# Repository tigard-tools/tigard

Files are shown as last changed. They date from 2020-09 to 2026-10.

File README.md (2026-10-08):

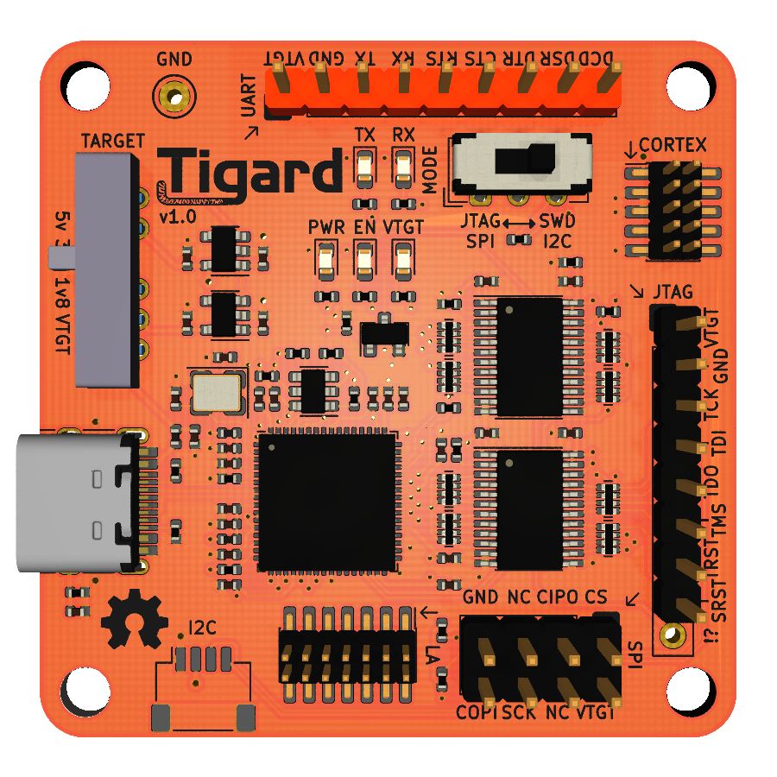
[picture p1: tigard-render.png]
Tigard PCB Render


# Tigard

An FTDI FT2232H-based multi-protocol tool for hardware hacking.

# Objectives

There are plenty of -232H series breakout boards, but they are generally designed to be an easy way to adapt it to a specific use, and not designed for regularly plugging in to all different target systems.

The two exceptions are the Exodus Intelligence Hardware Interface Board which is not open hardware or commercially available, and [TIMEP](https://github.com/Matir/timep) which is the origin and heritage of this project.

# Contents
- [Software Features](#software)
- [Hardware Features](#hardware-features)
- [Usage](#usage)
  - [Hardware Hookup](#hardware-hookup)
  - [Switches](#switches)
  - [UART](#uart)
  - [SPI](#spi)
  - [I2C (on I2C or SPI header)](#i2c-on-i2c-spi-or-jtag-header)
  - [JTAG Debug (on JTAG or CORTEX header)](#jtag-debug-on-jtag-or-cortex-header)
  - [JTAG Boundary Scan (on JTAG or CORTEX header)](#jtag-boundary-scan-on-jtag-or-cortex-header)
  - [SWD (on CORTEX header)](#swd-on-cortex-header)
  - [iCE40 Programming](#ice40-programming)
  - [AVR ISP](#avr-isp)
- [Debugging](#debugging)
- [Pinouts](#pinouts)
- [Stripes and Tails](#stripes-and-tails)
- [Dens (cases)](#dens)
- [Serial Numbers](#serial-numbers)
- [Getting Tigard](#getting-tigard)

# Software Features

In general, Tigard was designed to work as-is with several tools and libraries that already support the x232H family of chips. This includes:

* USB-Serial drivers for UART access
* OpenOCD and URJTAG for JTAG
* Flashrom, libmpsse, pyftdi and other tools for SPI interfaces
* libmpsse and pyftdi for I2C interfaces
* iceprog for ice40 FPGAs
* avrdude for AVR microcontrollers

Also, users have used Tigard with [Mitou jtag](/../../issues/79), [VSCode](/../../pull/75), and [SPI via FTDI](/../../issues/40)

# Hardware Features

Highlights:

* Dual-port, with one dedicated to UART and the second shared with other interfaces
* High-performance directional level shifters for 1.8 to 5.5v operation
* Switch to choose between on-board 1.8, 3.3, and 5.0v supplies and vTarget
* Switch to choose between SPI/JTAG and I2C/SWD modes
* Logic analyser port to observe device-level signals (v1.0 and later)
* Indicator lights to aid debugging

# Usage

## Hardware Hookup

Starting with the board completely disconnected:

1. Connect board to target system with clips or jumper wires
1. Select the correct mode either SPI/JTAG or SWD/I2C
1. Ensure that the voltage switch is in VTGT mode
1. Plug in the USB cable. The PWR and EN LEDs will illuminate
1. Power on your target.
1. If you connected VTGT to your target, the VTGT LED will illuminate. If not, you can now select your voltage with the voltage switch

## Switches
There are two switches on Tigard to set the mode of operation. One controls voltage, one controls how several of the IO pins are wired. Both need to be set properly for a specific use mode. Details are in each of the interface sections further below, but here is a summary of the modes and their uses:

#### Voltage Switch

This switch chooses the reference voltage for the level shifters and the target system:
* 1V8, 3V3, and 5V all apply a voltage to the VTGT pin.
* VTGT disconnects the VTGT pin from supplies, and depends on the wire connected to the target to set the level shifter voltage.

This results in 3 distinct use cases:
1. **Target-Powered:** Set the switch to VTGT and connect the VTGT wire to the **powered** target. The **target** powers the level shifters.
1. **Tigard-Powered:** Set the switch to a voltage, and connect the VTGT to the **unpowered** target. **Tigard** supplies power to the target.
1. **Self-Powered:** Set the switch to a voltage, but do NOT connect the VTGT wire. **Tigard** powers its own level shifters. **Target** powers itself.

#### Mode Switch

This switch controls how some of the I/O pins are connected for specific uses:

* When set to JTAG/SPI mode:
  * All signals run straight through
  * CORTEX and JTAG headers are wired for normal JTAG
  * JTAG and SPI headers can be used for SPI
* When set to SWD/I2C mode:
  * DO and DI are wired together to create SWDIO or SDA
  * CORTEX and JTAG headers can be used for SWD
  * JTAG and SPI headers can be used for I2C

## UART

#### Hookup:

* In most cases, you need pins 2,3,and 4 of the UART header - Ground, TX, and RX. Connect these to your target
* If you have a VCC header on your target, connect pin 1 - VTGT to it, and slide the voltage selector to VTGT
* If you don't have a VCC header, leave the VTGT wire disconnected, and choose your target voltage with the selector

#### Software:

The first of the two ports is connected to the UART header. When you plug Tigard in, you will see two serial devices show up - the first one is the one you want. Start your software using the appropriate serial port. For example:

```bash
screen /dev/ttyUSB0 115200
```

## SPI

#### Hookup:

The SPI/I2C header is laid out to be the same orientation as the pins on a standard 8-pin SPI flash chip, making it easy to attach clips or sockets.

* Select SPI/JTAG on the mode selection switch
* Connect your clip or socket to the header. Pay attention to pin 1, which is usually marked on sockets or has a red/highlighted wire on ribbon cables
* Connect your clip to the target or insert your chip into the socket
* If you're doing this in-circuit, you *must* take extra precautions to make sure no other device is communicating with the SPI device.
* If you're using a clip in-circuit and the target is powered on, choose the VTGT option on the voltage slider
* If you're using a zif socket, or clip with a powered-off target, choose the voltage on the voltage slider. 

#### Software:

flashrom is the most common tool for SPI flash dumps. However, while pervasive, it is very slow and inefficient.

```bash
flashrom -p ft2232_spi:type=2232H,port=B,divisor=4
```

libmpsse is a powerful library for controlling the MPSSE, or high speed serial pins of the x232H series. However, it is no longer recommended because of a large number of dependencies

pyftdi is a new and simple interface very similar to libmpsse:

```python
from pyftdi.ftdi import Ftdi
Ftdi.show_devices()
from os import environ
ftdi_url = environ.get('FTDI_DEVICE', 'ftdi://ftdi:2232:1:23f/2')
from spiflash.serialflash import SerialFlashManager
flash=SerialFlashManager.get_flash_device(ftdi_url)
print("Flash device: %s @ SPI freq %0.1f MHz" % (flash, flash.spi_frequency/1E6))
f=open("data.bin","wb")
f.write(flash.read(0,len(flash)))
f.close()
```

## I2C (on I2C, SPI, or JTAG header)

#### Hookup:

The I2C header (on hardware versions 1.0 and later) is compatible with [Sparkfun's Qwiic](https://www.sparkfun.com/qwiic) and [Adafruit's STEMMA QT](https://learn.adafruit.com/introducing-adafruit-stemma-qt/what-is-stemma-qt) system:

* Connect a 4-pin JST SH compatible cable into the I2C connector
* Connect the other end to your STEMMA QT, Qwiic, or other I2C device

In addition, the SPI header is laid out to be the same orientation as the pins on most 8-pin I2C chips, making it easy to attach clips or sockets:

* Connect your clip or socket to the header. Pay attention to pin 1, which is usually marked on sockets or has a red/highlighted wire on ribbon cables
* Connect your clip to the target or insert your chip into the socket

Finally, the JTAG header can also be used to get the I2C signals on .1" individual pins:

* Connect the 8-wire JTAG harness to the JTAG connector
* Connect the white SCL and grey SDA wires to your target's I2C pins

In either case, you need to set the Tigard switches properly:

* Select I2C on the mode selection switch
* If you're attaching to a device in-circuit and the target has its own power, choose the VTGT option on the voltage slider
* If you're attaching a standalone sensor, socket, or clip with a powered off target, choose the correct voltage on the voltage slider

#### Quirks:

The FT2232H has a very limited I2C implementation. I2C depends on shared I/O lines using open collector/open drain instead of push-pull-tristate I/O, but the FT2232H doesn't support that well. Therefore:

* Only controller operation is supported, not Device
* Tigard may not play nice if there are other controllers present on the I2C interface
* Clock stretching is not supported
* The I2C switch ties the DI and DO lines together so that it can do bidirectional communication
* The pullup resistors are not included since they are usually located on the target, and the weak pullups on the level shifters are sufficient

#### Hacks:

To accomodate both I2C and SWD, the DI and DO lines are combined through resistor R16. This is required for SWD and generally acceptable for I2C. 

Many I2C targets already have pullup resistors. In addition, all of Tigard's I/O pins have a weak 100K ohm pullup. In testing, this has been sufficient for both in-circuit and external use of most I2C devices. If you need stronger pullups on I2C, you can temporarily add them by pulling up COPI and SCK on the SPI header, or TCK and TDI on the JTAG header.

#### Software:

libmpsse is a powerful library for controlling the MPSSE, or high speed serial pins of the x232H series. However, it is no longer recommended because of a large number of dependencies

pyftdi is a new and simple interface very similar to libmpsse:

```python
from pyftdi.ftdi import Ftdi
Ftdi.show_devices()
from os import environ
ftdi_url = environ.get('FTDI_DEVICE', 'ftdi://ftdi:2232:1:23f/2')
from i2cflash.serialeeprom import SerialEepromManager
flash = SerialEepromManager.get_flash_device(ftdi_url,'24AA32A',0x50)
flash.write(5,10)
flash.read(0,32)
```

## JTAG Debug (on JTAG or CORTEX header)

#### Hookup:

The JTAG header is laid out with pins in the same order as the FTDI I/O pins are labeled, in order to be consistent with many other x232H breakout boards.

In additon, the CORTEX header is also wired as a standard ARM 10-pin JTAG header.

Be sure to select JTAG on the mode selection switch. This makes sure that TDI and TDO are separated, and ensures that TMS is wired properly to the CORTEX header. Otherwise, the standard hookup sequence applies.

#### Software:

[OpenOCD](https://openocd.org/) is a powerful tool for On-Chip Debugging of ARM, MIPS, and some other architectures.

**NOTE: These OpenOCD configs require OpenOCD v0.12+**. Previous versions may use the now-deprecated commands last updated in [this commit](https://github.com/tigard-tools/tigard/commit/5e5722944c8c1ec73b0fa85d574793300c23b3ce). [Future versions will deprecate some of these commands](https://github.com/tigard-tools/tigard/pull/86).

The appropriate configuration file (make this a link to the file) should look like:

```
adapter driver ftdi
transport select jtag
ftdi vid_pid 0x0403 0x6010
ftdi channel 1
adapter speed 2000
ftdi layout_init 0x0038 0x003b
ftdi layout_signal nTRST -data 0x0010
ftdi layout_signal nSRST -data 0x0020
```

To use it with openocd:

```bash
openocd -f tigard-jtag.cfg
```

[Black Magic Debug](https://codeberg.org/blackmagic-debug/blackmagic) is an alternative for OpenOCD that supports automatic identification and configuration of a huge number of devices. The Black Magic Debug App can do this through Tigard:

```
blackmagic -l # list probes, you should see Tigard listed
blackmagic -c tigard -t # list connected devices, you should see your target
blackmagic -c tigard # start the server, it will tell you a port to connect GDB to
gdb-multiarch --eval-command="tar ext :2000" --eval-command="att 1" # to start gdb and connect
```

## JTAG Boundary Scan (on JTAG or CORTEX header)

Boundary scan can be used to take control of a device to set I/O pin state (`EXTEST`), or to view the state of them during device operation (`SAMPLE`).

#### Hookup:

The hookup is the same as described in section [JTAG Debug (on JTAG or CORTEX header)](#jtag-debug-on-jtag-or-cortex-header).

The pinout is compatible with the `Olimex ARM-USB-OCD` running on the `B` interface.

#### Software:

[UrJTAG](https://urjtag.sourceforge.io/) is open-source jtag control software geared toward low-level and boundary scan use.

We need to tell UrJTAG Tigard's VID and PID, as well as the fact that JTAG is on interface 1 (default is 0). Due to a bug it seems that TCK is miscalculated and is actually running 5 times what you select - 500khz in the case below.

```
jtag> cable ft2232 vid=0x403 pid=0x6010 interface=1
Connected to libftdi driver.
jtag> frequency 100000
Setting TCK frequency to 100000 Hz
jtag> detect
IR length: 5
Chain length: 1
Device ID: 00010110001101010010001001001111 (0x1635224F)
  Unknown manufacturer! (00100100111) (/usr/share/urjtag/MANUFACTURERS)
jtag> 
```

The [TopJTAG](http://www.topjtag.com/) software is one of the easier to use options, but is commercial ($100) and Windows-only. This includes a "waveform view" that allows you to view arbitrary pin states as if you had a logic analyzer on the device while it is running. If using TopJTAG, set the following as the JTAG connection:

* `Connection`: Generic FTDI FT2232
* `Device`: Tigard V1.0 B
* `Static Pins`: Olimex ARM-USB-OCD
* `TCK Freq`: 2 MHz (adjust as needed)

An open-source option that supports Tigard is [JTAG Boundary Scanner](https://github.com/viveris/jtag-boundary-scanner) which offers a Windows GUI, but the backend library is cross-platform (however written in C). This library offers many features such as an ability to talk to SPI devices attached to the target chip, where the SPI interface is run using JTAG boundary scan (warning - slow!). 

Alpha Python bindings for this library are available in [PyJTAGBS](https://github.com/colinoflynn/pyjtagbs). Using Tigard from Python for checking the scan chain for example:

```python
from jtagbs import JTAGCore, JTAGBS

interface = JTAGCore()
jtag = JTAGBS(interface)

probes = jtag.list_available_probes()
print(probes)

jtag.open_probe('Tigard V1.0 B')
jtag.init_scanchain()

print(jtag.list_devids())
```

See the PyJTAGBS documentation for further examples of loading BSDL files required to toggle specific pins. The listed probes should be `'Tigard V1.0 A TG100065A'` and `'Tigard V1.0 B TG100065B'` if the correct drivers are loaded.

## SWD (on CORTEX header)

#### Hookup:

The SWD header a standard 10-pin header found on many SWD target boards. A short 'SWD' cable with the same header on both ends is the ideal way to hook up to most targets.

Be sure to select SWD on the mode selection switch. This connects the DI and DO pins with resistor R16 to make the bidirectional SWDIO pin, and connect it to pin 2 of the CORTEX header. Otherwise, the standard hookup sequence applies.

#### Software:

**NOTE: These OpenOCD configs require OpenOCD v0.12+**. Previous versions may use the now-deprecated commands last updated in [this commit](https://github.com/tigard-tools/tigard/commit/5e5722944c8c1ec73b0fa85d574793300c23b3ce).

OpenOCD is a powerful tool for On-Chip Debugging of ARM, MIPS, and some other architectures. In order to use it for SWD with Tigard, you'll need to build it from source. The [directions from the AND!XOR DC27 Badge](https://hackaday.io/project/164346-andxor-dc27-badge/log/166464-swd-all-the-things) cover it step-by-step.

The appropriate configuration file (make this a link to the file) should look like:

```
adapter driver ftdi
transport select swd
ftdi vid_pid 0x0403 0x6010
ftdi channel 1
adapter speed 2000
ftdi layout_init 0x0028 0x002b
ftdi layout_signal SWD_EN -data 0
ftdi layout_signal nSRST -data 0x0020
```

To use it with openocd:

```bash
openocd -f tigard-swd.cfg
```

## iCE40 Programming
The Lattice iCE40 family of FPGAs are popular for small scale projects because of their low cost and the availability of an open toolchain. While this is a *very* specific target, Tigard is well suited for programming devices since it has all the necessary pins readily available.

#### Hookup:
All the necessary pins are on the JTAG header. 
The bonus "!?" pin is not populated by default. The JTAG !? pin and the UART RX pin are shorted in case you need to flash an iCE40 but don't want to solder your Tigard. See the pinouts table below for details.

Be sure to select JTAG/SPI on the mode selection switch. This makes sure that COPI and CIPO are separated.

If you are planning on programming SRAM instead of FLASH:
* Swap COPI and CIPO
* Disconnect CS from your FLASH, but leave it attached to the iCE40.

#### Software:
To program your target's nonvolatile FLASH, use iceprog:
```
iceprog -I B yourbitstream.bin
```
If you prefer to directly program the ice40's SRAM, make sure you adjust your wiring and again use iceprog:
```
iceprog -I B -S yourbitstream.bin
```
Remember that if you choose to program the SRAM, your bitstream will be lost on power cycle.

## AVR ISP
To program AVR microcontrollers including many Arduino boards, use avrdude with a custom configuration file.

#### Hookup:
Be sure to select JTAG/SPI on the mode selection switch. Use SRST as your reset.

#### Software:
Avrdude is an open-source AVR flashing utility. Avrdude 7.1 and later have built-in support for Tigard - all you need to do is:
```
avrdude -c tigard
```

For older versions, create the following `tigard.conf` file in order to identify Tigard as an avrftdi-compatible device and specify which pins to use:
```
programmer
  parent "avrftdi"
  id = "tigard";
  desc = "Tigard interface board";
  usbdev = "B";
  sck = 0;
  mosi = 1;
  miso = 2;
  reset = 5;
;
```

Then, use `-C +tigard.conf` to add the configuration file, and `-c tigard` to indicate your programmer:
```
avrdude -C +tigard.conf -c tigard
```

# Debugging

#### PWR LED:

This will turn on when the board has USB power and should turn on immediately when the USB cable is connected.

* If it does *not*, then check your USB cable and power supply.
* If it comes *on then goes off*, is *dim*, or *flickers*, then you have likely shorted power or ground somewhere with your wires or your target.

#### EN LED:

This will turn on when the FTDI chip is operation and should turn on a moment after the usb power LED is on.

* If it does *not* come on, you may have a faulty USB cable, a power-only USB port or cable, or a bad FTDI chip

#### VTGT LED:

This will turn on when the level shifters are properly powered, either by your target or by the onboard level selector

* If you are in VTGT mode, and it does *not* come on, check your target power and your power and ground wiring to the target
* If you are selecting a voltage and it does *not* come on, you have likely shorted power or ground somewhere with your wires or target.
* There are corner cases where VTGT will get [latched to a voltage applied to an output pin](https://github.com/tigard-tools/tigard/issues/20). Establishing a habit of always starting with VTGT off will help avoid this.

#### ALL LEDS ON:

When all LEDS are on, then Tigard is probably working as intended. If you are still having trouble, there are a few possibilities. They are listed in order of likelihood, though it makes sense to test the easier cases first:

* It's a *wiring* issure. Make sure your wires are connected well. Confirm with a multimeter.
* It's a *target* issue. Try a different target to make sure your software is working properly
* It's a *software* issue. Try a different software tool or mode to make sure your board works properly
* It's a *protocol* issue. Observe your signals with a logic analyzer or oscilloscope to make sure they're correct
* It's a *hardware* issue. Try a different Tigard board to see if it persists
* It's a *tigard* issue. Try a different x232H board to see if it persists

# Pinouts

There are way too many choices of 'standard' pinouts for all of these interfaces. Pinouts were chosen for ease of use, specificially:

* If there's a well established and used standard, use it (SWD)
* If there's a predominant primary usage that would be easier, use it (SPI/I2C)
* If there are other common boards with pinouts, use them (UART and JTAG)

### UART

2.54mm pitch. 1x9 pin header.

This pinout prioritizes putting the FT2232H pins in sequential order - similar to many x232H breakout boards

The coloring of VTGT, GND, TX, and RX is intended to match most common usb-serial cables. The remaining wires are included, but not installed on the header, so users can optionally install them.

| Pin Number | UART Signal | Color | FT2232H Pin |
| --- | --- | ----- | --- |
| 1 | VTGT | Red | -- |
| 2 | GDD | Black | -- |
| 3 | TX | Green | AD0 |
| 4 | RX | White | AD1 |
| 5 | RTS | -- | AD2 |
| 6 | CTS | -- | AD3 |
| 7 | DTR | -- | AD4 |
| 8 | DSR | -- | AD5 |
| 9 | DCD | -- | AD6 |

### SWD

1.27mm pitch. 2x5 pin header.

This is a standard pinout. In order to accomodate both SWD and JTAG, the mode switch:

1. Combines DI and DO to create SWDIO for SWD mode
2. Selects between SWDIO and TMS for pin 2

| Pin Number | SWD Signal | FT2232H Pin | JTAG Signal | FT2232H Pin |
| --- | --- | --- | --- | --- |
| 1 | VTGT | -- | VTGT | -- |
| 2 | SWDIO | BD1 BD2 | TMS | BD3 |
| 3 | GND | -- | GND | -- |
| 4 | SWDCLK | BD0 | TCK | BD0 |
| 5 | GND | -- | GND | -- |
| 6 | NC | -- | TDO | BD2 |
| 7 | KEY | -- | KEY | -- |
| 8 | NC | -- | TDI | BD1 |
| 9 | GND | -- | GND | -- |
| 10 | nSRST | BD5 | nSRST | BD5 |

### JTAG

2.54mm pitch. 1x8 pin header.

This pinout prioritizes putting the FT2232H pins in sequential order - similar to many x232H breakout boards. 

In general, set the mode switch to SPI/JTAG mode when using this connector.

The coloring of the wiring harness is what [SecuringHardware.com](https://SecuringHardware.com/) used for their Adafruit FT232H wiring harness for several years. The colors were chosen because frequently black-brown-red-orange are used with logic analyzers in class, so unique colors were chosen for this wiring harness.

This header can also be used for I2C and SPI if the 8-pin header doesn't make sense in your application.

| Pin Number | JTAG Pin | Color  | FT2232H Pin |
| --- | --- | --- | --- |
| 1 | VTGT | Red | -- |
| 2 | GND | Black  | -- |
| 3 | TCK | White  | BD0 |
| 4 | TDI | Grey | BD1 |
| 5 | TDO | Purple | BD2 |
| 6 | TMS | Blue | BD3 |
| 7 | TRST | Green  | BD4 |
| 8 | SRST | Yellow | BD5 |

### SPI

2.54mm pitch. 2x4 pin header.

This header is designed specifically to match the pinout of most 8-pin SPI and I2C chips, so that a jumper to a chip clip or a socket would align properly.

In order to accomodate both SPI and I2C, the mode switch:

1. Combines DI and DO to create SDA for I2C mode
2. Disconnects pin 2 in I2C mode for devices that use it as an address signal

| Chip Pin Number | Header Pin Number | SPI signal | FT2232H Pin |
| --- | --- | --- | --- |
| 1 | 1 | CS | BD3 |
| 2 | 3 | CIPO | BD2 |
| 3 | 5 | WP | pullup |
| 4 | 7 | GND | -- |
| 5 | 8 | COPI | BD1 |
| 6 | 6 | SCK | BD0 |
| 7 | 4 | EN | pullup |
| 8 | 2 | VTGT | -- |

### LA

1.27mm pitch. 2x7 pin header.

The LA port makes it easier to hook up a logic analyzer to monitoring push-pull signals between Tigard and your target hardware. It's tested and working well with UART, SPI and JTAG, and generally works with I2C. 

While there is a driver allowing you to use the FT2232H as a makeshift logic analyzer, that's not the intended purpose - the expected use case is that you are using Tigard to communicate with a target, but need to debug that communication using an external logic analyzer.

The LA port may be used as a passive mechanical adapter although this usage is [not supported](https://github.com/tigard-tools/tigard/issues/20). For best results, power the Tigard board but disconnect VTGT from the target. Additional effort will likely be required to ensure signal integrity.

This header is specifically designed to connect directly to the Bitmagic logic analyzer, or you could use the Bitmagic logic analyzer wiring harness to connect to any other tool.

The 8 most interesting signals are connected - 6 from the JTAG/SWD/SPI/I2C port, and 2 from the UART port.

| Pin Number | Bitmagic Signal | FT2232 Pin | JTAG signal | SPI signal | SWD Signal | I2C Signal | UART Signal |
| --- | --- | --- | --- | --- | --- | --- | --- |
| 1 | xPB0 | BD0 | TCK | SCK | SWCLK | SCL |
| 2 | xPB1 | BD1 | TDI | COPI | SWDIO | SDA |
| 3 | xPB2 | BD2 | TDO | CIPO | SWDIO | SDA |
| 4 | xPB3 | BD3 | TMS | CS | |
| 5 | xPB4 | BD4 | TRST |
| 6 | xPB5 | BD5 | SRST |
| 7 | xPB6 | AD0 | | | | | TX |
| 8 | xPB7 | AD1 | | | | | RX |
| 9 | GND |
| 10 | GND |
| 11 | xTRIG |
| 12 | xCLK |
| 13 | xTRIG2 |
| 14 | xIFCLK |

### I2C

1mm pitch. 1x4 pin header. JST SH compatible.

This header is designed specifically to match [Sparkfun's Qwiic](https://www.sparkfun.com/qwiic) and [Adafruit's STEMMA QT](https://learn.adafruit.com/introducing-adafruit-stemma-qt/what-is-stemma-qt) system.

Set the mode switch to I2C/SWD mode when using this connector.

| Pin Number | I2C signal | FT2232H Pin |
| --- | --- | --- |
| 1 | GND | --- |
| 2 | VCC | --- |
| 3 | SDA | BD1 and BD2 |
| 4 | SCL | BD0 |

### iCE40
Use the JTAG header with the addition of the "!?" pin which is not populated by default.

| Pin Number | Label | iCE40 Signal | FT2232 Pin  |
|---|---|---|---|
| 1 | VTGT | VTGT | ---
| 2 | GND | GND | ---
| 3 | TCK | CLK | BD0
| 4 | TDI/MOSI/SDA | MOSI/COPI | BD1
| 5 | TDO/MISO/--  | MISO/CIPO | BD2
| 6 | TMS/SS/-- | --- | ---
| 7 | TRST/--/-- | CS/ICE_SS_B | BD4
| 8 | SRST/--/-- | CRESET | BD5
| 9 | !? | CDONE | BD6

JTAG !? pin and the UART RX pin are shorted in case you need to flash an iCE40 but don't want to solder your Tigard.

### AVR ISP
The common 6-pin ICSP header found on many AVR boards requires the following hookup:

| Pin Number | Label | ISP Signal | ICSP Pin | FT2232 Pin  |
|---|---|---|---|---|
| 1 | VTGT | VTGT | 2 | ---
| 2 | GND | GND | 6 | ---
| 3 | TCK | SCK | 3 | BD0
| 4 | TDI/MOSI/SDA | MOSI | 4 | BD1
| 5 | TDO/MISO/--  | MISO | 1 | BD2
| 6 | TMS/SS/-- | --- | --- | ---
| 7 | TRST/--/-- | --- | --- | ---
| 8 | SRST/--/-- | RST | 5 | BD5

# Stripes and Tails
In order to support different interfaces, custom wiring harnesses or add-on boards might be useful. The preferred names are "Tigard Stripes" for add-on boards and "Tigard Tails" for wiring harnesses.

* The `UART Tail` ships with Tigard and includes VTGT, GND, TX and RX
* The `JTAG Tail` ships with Tigard and includes labeled multipurpose JTAG, SPI, and I2C wires
* The `SOIC8 Tail` refers to inexpensive SOIC-8 clips with ribbon cables and 2x4 connectors compatible with the SPI/I2C header

# Dens
Tigard is supplied as a bare board, but there are several options for 3d printing mounts and cases - 'dens' - for your Tigard.:

* The first [TigarDen](https://github.com/hamid-elaosta/TigarDen) by hamid is a multi-piece top and bottom case for holding tigard
* A [bottom-only case](https://www.thingiverse.com/thing:5166570) by phaktor has neat tiger stripes on the bottom, or can be printed in a single color
* A [hinged case](https://www.thingiverse.com/thing:5169952) by professor_plum holds a tigard, bitmagic, and several probes
* A [simplified 2-piece case](https://cad.onshape.com/documents/832906f0b96360664fedfe62/w/f1b917fd93e5b559c0927cf4/e/eb5666e6e328afd821567f83) by jwise for milling or printing
* [tigard-tray](https://github.com/tigard-tools/tigard-tray) is a 3d printed tray that holds tigard, bitmagic, and 9 probe clips while protecting the pins, so that it can slide in and out of a mesh pocket in a zippered case.

# Serial Numbers

Tigard follows a convention for allocating serial numbers. If you decide to make and sell your own Tigards, please change the first two characters "TG" to something else.

Format: `TGMmxxxx`

* `TG` - constant indicates "tigard"
* `M` - major version decimal number
* `m` - minor version decimal number
* `xxxx` - 0 padded lowercase hex serial starting at 0

## Allocated

* First batch of 28 (Jul 5, 2020): TG010000 - TG01001b
* Second batch of 42 (Aug 5, 2020): TG01001c - TG010046
* Third batch of 496 (October 2020): TG100000 - TG1001f0
* Fourth batch of 693 (January 2021): TG110000 - TG1102b5
* Fourth batch of 697 (September 2021): TG110400 - TG1106b9<br>Note: This batch's through hole components were not soldered with a selective solder wave machine. Some needed rework because the "hack" jumper was accidentally bridged with solder.
* Fifth batch of 1400 (Nov 2022): circa TG110700 - TG110c7f
* Sixth batch of 1400 (Jan 2024): circa TG110c80 - TG 1111ff <br>Note: This batch had the jtag header assembled in the wrong position. It's supposed to be an 8 pin header in a 9 hole footprint. Pin 9 of the footprint should be vacant - it's a special purpose pin only there for flashing ice40 fpgas like icebreaker. However, pin 1 was mistakenly left vacant instead. I added a header in pin 1 and trimmed pin 9 them so that the 8-pin jtag wiring harness can't be put on wrong and so the 9-pin uart header is not accidentally put there.
* Seventh batch of 2100 (Jan 2025): circa TG111200-TG111834

# Getting Tigard
## Where to Buy
Tigard can be purchased directly from [Crowd Supply](https://www.crowdsupply.com/securinghw/tigard), [Mouser](https://www.mouser.com/ProductDetail/Securing-Hardware/TIGARD-V1?qs=aP1CjGhiNiFnjSEE%2FnXyEw%3D%3D), or [1BitSquared](https://1bitsquared.com/collections/embedded-hardware/products/tigard)

[HackerWarehouse](https://hackerwarehouse.com/product/tigard/) also has a [laser-cut acrylic case](https://hackerwarehouse.com/product/tigard-case/) designed by SynapticRewrite

Tigard can be aquired in Europe via [1BitSquared's German store](https://1bitsquared.de/products/tigard)

10+ boards can be ordered at a discount direct from [SecuringHardware.com](https://learn.securinghardware.com/product/tigard/). Contact tigards - at - securinghw.com for wholesale orders.

## DIY Tigards
Tigard is published with the [CC-BY-SA 4.0 License](https://github.com/tigard-tools/tigard/blob/master/LICENSE.txt). This means you have permission and are encouraged to make your own devices, or make modifications to the Tigard design, as long as you attribute the project and share your changes.

If you choose to manufacture your own tigard boards, we recommend/request the following:
* Physically differentiate your boards somehow - choosing a different color is likely easiest - so they are not mistaken for boards from SecuringHardware.com
* You are welcome to call them "Tigard" and program that into the usb product descriptor in the EEPROM
* Program accurate manufacturer information in usb manufacturer descriptor the EEPROM
* Use serial numbers that do not conflict with the ones [noted above](#serial-numbers) - do not use the 'TG' prefix

SecuringHardware.com tests, verifies, and supports every Tigard they manufacture and sell. Please let us know about any [design issues](https://github.com/tigard-tools/tigard/issues) while making your own devices, but if you're having hardware issues with a third-party Tigard that you bought, you will need to resolve that with the seller or manufacturer.

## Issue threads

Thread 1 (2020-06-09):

I2C header wiring is incorrect

securelyfitz, 2020-06-09:
There are diodes between the SDA/SCL pins and the CK/DI/DO pins to protect JTAG and SPI from the I2C pullups.

Unfortunately these diodes prevent I2C device's response from getting back to the FT2232H - When trying to read an I2C eeprom, using the SPI header works, using the I2C header does not.

The FT2232H doesn't do real push-pull, it ties in and out wires to each pin to make it work.

1. Since we don't support clock stretching (at least, the hardware doesn't - if that should change, separate issue), then we can remove the diode and pullup on SCL.

2. Since we already have a dual pole switch to combine DI and DO for both I2C and SWD, we can use the second pole to switch in a pullup

3. The remaining difference between SPI and I2C headers are CS and MISO. Some 8 pin I2C chips use those pins for address bits. AFAIK those are only checked at poweron, but i haven't tested and wouldn't be surprised if they mess with other devices. CS is unused in I2C mode, but MISO could theoretically interfere. Perhaps the I2C/SWD switch could also disconnect the spi header MISO pin with no additional hardware?

I can bluewire whatever changes we decide on to make sure they work - and perhaps also experiment with removing the SDA pullup entirely?

securelyfitz, 2020-06-11:
Test: pulling off diodes and pullups, I2C still works fine both with bare devices and in-circuit. Likely works because 1) in-circuit has pullups on the target and 2) bare device, the level shifter is sensitive enough that the 100k pullups are sufficient.

securelyfitz, 2020-06-11:
So, confirmed todo:
1. remove i2c header
2. remove i2c diodes and pullups
3. rotate SPI header so even numbered pins face board edge

breaking off switch options to separate issue #5

Closed 2020-06-17.

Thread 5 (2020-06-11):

revise mode selection switch

securelyfitz, 2020-06-11:
Right now the mode selection switch is a DPDT but we're only using half of it:
SPI/JTAG: DO and DI separated
SWD/I2C: DO and DI connected with resistor

We have three features worth considering for the second half of the switch:
1. Adding an I2C pullup on SDA
Theoretically this is necessary for I2C to work, but due to FT2232H's poor i2c implementation it doesn't actually matter. There may be corner cases where it does, but for those cases, a user can put a resistor between pins 1 and 4 of the JTAG header to get this done.

2. Disconnecting MISO from the SPI/I2C header in I2C mode
Theoretically this causes issues for i2c chips that use pin2 as their address input. I haven't encountered issues, perhaps because most devices latch their address bits at powergood and they're ignored after. The fix to this is not connecting that pin to the target system, defeating the convenience of the I2C header.

3. Swapping between TDO and TMS on pin **_2_** of the SWD header
This allows using the swd connector as a 10 pin arm jtag connector as well.  (edit: fixed wrong pin)

Options 1 and 2 are choosing to protect against a unknown risks in the least frequently used interface that's avoidable with inconvenience. Option 3 is adding support for a frequently used feature for a large audience.

I'm leaning toward option 3, but only if both @esden and @fharding1 feel that it's worth the risk that avoiding options 1 and 2 would mitigate.

securelyfitz, 2020-06-11:
Wait, does this work using only one switch:
SPI/JTAG: DO connected to MOSI
SWD/I2C: DO connected to DI via swd resistor

Who knew switches were so hard. Maybe i'm just getting old.

securelyfitz, 2020-06-11:
More details:
MISO really does need to be disconnected, but luckily that can be done with only one switch like mentioned above:
> SPI/JTAG: DO connected to MOSI
> SWD/I2C: DO connected to DI via swd resistor

My current thought is that option 2 is mandatory but doable on the first switch, and option 3 is the best choice for the second leg of the switch.

securelyfitz, 2020-06-12:
updating - tms/swdio is pin 2 of the swd connector.

fharding1, 2020-06-14:
> My current thought is that option 2 is mandatory but doable on the first switch, and option 3 is the best choice for the second leg of the switch.

I think I agree, just to clarify:

The first pole will connect DO to either MOSI or DI via the SWD resistor, and the second pole will connect pin 2 of the SWD header to either TDO or TMS.

securelyfitz, 2020-06-14:
Just to remove ambiguity - When switched, both the SPI header and the JTAG header (and i guess swd too) should have the correct wiring. The JTAG header is primarily for jtag, but in general, the wiring harness will also be used when trying to flywire connect to spi tespoints - not the 8-pin header which will most likely be exclusively for clips and sockets.

So:
BD2 enters the ftdi via the level shifter, via what is now DI TDO MISO SWDIO
After change, it should be just DI

First Pole:
When in JTAG+SPI mode, the switch shorts DI to TDO MISO
When in SWD+I2C mode, the switch shorts DI to SWDIO, which connects to DO TDI MOSI via resistor, currently R16
**this affects the SPI, JTAG, and SWD headers**

Second Pole:
When in JTAG+SPI mode, Pin2 of the swd header is shorted to TMS
When in SWD+I2C mode, Pin2 of the swd header is shorted to SWDIO
**this only affects the SWD header. SPI and JTAG are unaffected**

Dilemma:
Ideally in I2C mode, there's no R16 resistor, but we need it for SWD.
Since we need the resistor, ideally, DI TDO MISO SWDIO would be SDA.
However, on UNIT and V0.0, DO TDI MOSI connects to spi header pin 8 and this works fine as SDA

I don't think this is an issue. I also don't think that truly fixing it has a solution that doesn't require more parts. Really, we could to a 4-way JTAG-SPI-I2C-SWD switch even though it be mostly redundant, with the advantage of reducing # of unique parts at the cost of space.

fharding1, 2020-06-15:
> Dilemma:
Ideally in I2C mode, there's no R16 resistor, but we need it for SWD.
Since we need the resistor, ideally, DI TDO MISO SWDIO would be SDA.
However, on UNIT and V0.0, DO TDI MOSI connects to spi header pin 8 and this works fine as SDA
>
> I don't think this is an issue. I also don't think that truly fixing it has a solution that doesn't require more parts. Really, we could to a 4-way JTAG-SPI-I2C-SWD switch even though it be mostly redundant, with the advantage of reducing # of unique parts at the cost of space.

Could we add a SPDT solder jumper to the back of the board that normally routes DI through R16 but also allows you to cut the jumper, solder jump the other throw, and connect it directly?

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

securelyfitz, 2020-06-15:
i like this option. It does complicate the schematic - worth documenting in the schematic. But allows those who never use SWD and heavily use I2C to get the best I2C circuit.

Closed 2020-06-17.

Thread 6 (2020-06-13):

Missing pull-down resistor for REF mosfet

fharding1, 2020-06-13:

securelyfitz, 2020-06-15:
Have you prototyped this on hardware?

fharding1, 2020-06-15:
@securelyfitz yeah, all I had to do was solder a 47k (what I had on hand) between the MOSFET gate and source legs. Previously you could turn on the LED just by pressing your finger into the switch leads. My bodge fixed that.

Closed 2020-06-14.

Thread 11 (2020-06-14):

document V0.0 rework

securelyfitz, 2020-06-14:
What's the best place to do this? Release notes? somewhere else?

It won't matter much for all four V0.0 boards, but when new changes come around to future revisions, it would be helpful to have documentation somewhere for assembly/rework/functionality notes for them.

For V0.0, currently:
- I2C header, resistors, and diodes don't work and shouldn't be populated
- what resistor can be added where to fix #6

fharding1, 2020-06-14:
I tagged 289bb13b87d6e076d185519fd003d9ced033bb32 as v0.0, when we finish this next revision we can tag that commit as v0.1 (or whatever), look at all the commits between them, and annotate that tag with all the changes from v0.0.

I put those known issues in the v0.0 release: https://github.com/fharding1/tigard/releases/tag/v0.0

securelyfitz, 2020-06-15:
The level of detail i'm looking for is "If you want to get this working on a V0.0 board, solder an X ohm resistor between pin y of component z, as shown in the picture"
Where should that be captured?

fharding1, 2020-06-15:
@securelyfitz oh, I see. I think maybe we could add an "upgrade" section to the v0.1 release that documents how to bodge the previous revision. Were you thinking of doing this for all revisions, or just production (major revision > 0)?

I like semver's philosophy on this (even though we're not using true semver), it documents that "Major version zero (0.y.z) is for initial development. Anything MAY change at any time. The public API SHOULD NOT be considered stable." Which when applied here would pretty much imply if you got your hands on a major rev 0 board you shouldn't expect it to work or be well documented.

Closed 2020-06-23.

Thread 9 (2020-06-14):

Clarify VCC/VTGT/TARGET naming convention

securelyfitz, 2020-06-14:
Switch is labeled "target", headers are labeled "VCC", LED is labeled "REF", documentation and wiring harnesses i used "VTGT"

It should be consistent. Not sure what it should be. Arguments for each:

VCC: This is what all the pinouts will have it named normally. We label it MOSI not DI or BD2, so why would we make the voltage pin any different?

VTGT: reinforces that you're attaching to someone else's voltage (potentially)

Vx: Clarifies that it's not certain what voltage you're attaching

Switch label: "Target" probably makes sense here; If we go with VCC for the header pins, then the whole switch should probably be labeled the 'VCC selector' or 'Vcc switch' and either Target or TGT is fine.

Once deciding, be sure to update:
- Switch input label
- Switch device label
- Header labels
- LED label
- Jumper wire lables
- Documentation

securelyfitz, 2020-06-14:
aslo: VREF on the bottom vref/vtarget cuttable jumper.

While i think the easiest answer is to just label everything as it is in the schematic, i'm not sure that's the best answer for the novice end users who might be using the silkscreen text to make decisions.

fharding1, 2020-06-14:
I'm not a fan of VCC because it's unclear whether you're talking about Tigard's VCC (5v) or the target's VCC (5v, 3.3v, 1.8v, target). I haven't seen Vx before and I think that would just confuse me.

VTGT seems like the best option. It will look a little less elegant on the pinouts but it should be ok.

fharding1, 2020-06-14:
Is there a label that would make more sense for the jumper on the bottom? VREF/VTGT communicates that while normally the target and reference voltage are the same thing, you can isolate them from each other by cutting the jumper.

Closed 2020-06-17.

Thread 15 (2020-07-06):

explore feasibility of ice40 programming interface

securelyfitz, 2020-07-06:
ice40 needs ICE_CDONE and ICE_CRESET not currently connected:

from top to bottom, from FTDI perspective:
* ADBUS0 - ICE_SCK -> out
* ADBUS1 - FLASH_MOSI|IO0 -> out
* ADBUS2 - FLASH_MISO|IO1 <- in
* ADBUS3 - SPI_CS (optional, not used for programming) -> out
* ADBUS4 - ICE_SS_B -> out
* ADBUS5 - NC
* ADBUS6 - ICE_CDONE <- in
* ADBUS7 - ICE_CRESET -> out

Potential solution:
- BDBUS7 not currently attached to anything. no spare output buffer pins
- BDBUS5 is only used for JTAG/SWD SRST, which is only used by openocd, which is easily configurable via config file:
`ftdi_layout_signal nSRST -ndata 0x0020 -noe 0x0040` becomes `ftdi_layout_signal nSRST -ndata 0x0080 -noe 0x0040`
- BDBUS6 can connect to input buffer A6
- Input buffer input B6 can be tied to B1; the RX pin will be used as ICE_CDONE and see on both ADBUS1 and BDBUS6
- LA input can give access to all necessary pins

Note - downside: Can't use UART at the same time because RX would be clobbered.
Alternative would mean adding a pin somewhere. Perhaps just use one of the spare LA (trig/clk/etc) pins?

esden, 2020-08-08:
I have taken tigard V0.1 board and applied the modifications as proposed above.

Exactly as shown in this picture below:
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

I used a 2k2 resistor for the connection between BDBUS7 to BTBUS5.

I can confirm that this setup works and allows the use of iceprog to program an iCE40 Flash.
Example command invocation:
```
iceprog -I B bitstream.bin
```

A flywiring connection from Tigard to a ice40 target for the purpose of bitstream FLASH programming would be the following:
* GND - GND
* JTAG TDI - MOSI/COPI/IO0
* JTAG TDO - MISO/CIPO/IO1
* UART RX - CDONE
* JTAG SRST - CRESET
* JTAG TCK - CLK
* JTAG TRST - CS

Also tested if programming directly into the iCE40 SRAM works. I can confirm that it does. The following iceprog command can be used:
```
iceprog -I B -S bitstream.bin
```

Do not forget to disconnect the Flash CS jumper on your iCE40 target and to swap CIPO/COPI order, either with jumpers on your target or through wire swap. A wire swap would result in the following fly wire mapping from Tigard to iCE40 target:

* GND - GND
* JTAG TDI - MISO/CIPO/IO1
* JTAG TDO - MOSI/COPI/IO0
* UART RX - CDONE
* JTAG SRST - CRESET
* JTAG TCK - CLK
* JTAG TRST - CS

Regarding the pin mapping. It would be lovely to have a dedicated connector for this, but space is limited and ice40 is a fairly small target subset all things considered. I think the compromise where it is possible to make a logic analyzer connector to ice40 programmer cable is a reasonable trade off.

But in case a connector is considered in the future I would like to propose the following icebreaker-bitsy connector pinout:

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

This connector is a 0.1" (2.54mm) pitch 2x4 connector.

securelyfitz, 2020-08-08:
Seems like a small enough change that it's worth implementing the additional routing but not the header, though good to document it in case someone forks or revises.
@fharding1 let me know if it's not as straightforward as it looks or it's not feasible for other reasons.

fharding1, 2020-08-14:
@esden were you able to take a look at 0e0eb68?

securelyfitz, 2020-09-04:
awesome. assigning this to me to add to the docs.

securelyfitz, 2020-09-05:
documented in b602d86

Closed 2020-09-05.

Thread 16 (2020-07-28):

find a cheaper alternative for the samtek swd and LA connectors

securelyfitz, 2020-07-28:
the samtek ones are $$ even in quantity over 1/4 of the whole BOM cost for the two least-used connectors.

full shroud ones would obscure pcb labels.
no shroud would end up with backwards cables. Not the end of the world, but not good for a device designed for beginners.

adafruit seems to be able to get them and resell them cheaper than samtek, maybe super high volume? https://www.adafruit.com/product/4048

fharding1, 2020-07-31:
Unshrouded $0.49/PCS at 100+ https://lcsc.com/product-detail/Pin-Header-Female-Header_Amphenol-ICC_20021121-00010C4LF_Amphenol-ICC-20021121-00010C4LF_C150517.html
Shrouded $0.65/PCS at 100+ https://lcsc.com/product-detail/Pin-Header-Female-Header_Amphenol-ICC_20021221-00010C4LF_Amphenol-ICC-20021221-00010C4LF_C180221.html
Unshrouded THT (would require PCB changes) $0.46/PCS at 100+ https://lcsc.com/product-detail/Pin-Header-Female-Header_Amphenol-ICC_20021111-00010T4LF_Amphenol-ICC-20021111-00010T4LF_C239059.html

Only thing I'm not sure about is whether the center notch on that shrouded connector is large enough.

Droid-MAX, 2020-08-01:
Maybe someone needs this.

https://github.com/Droid-MAX/tigard/releases/tag/v0.1-20200731

securelyfitz, 2020-08-06:
I have one of these: https://www.digikey.com/product-detail/en/cnc-tech/3221-10-0300-00/1175-1735-ND/4878946
$0.40 at 1000+.

Physically about .5" wide - fits, but obscures JTAG and LA silk and there's almost no clearance by the corner mounting hole. Seems like moving

14-pin https://www.digikey.com/product-detail/en/cnc-tech/3221-14-0300-00/1175-1738-ND/4878947 for $0.57
Don't have one of these in hand, but looks like it would overlap a couple resistors btwn LA and SPI connectors.

Combined, saves several dollars - almost 25% on BOM cost and likely worth a little effort...

fharding1, 2020-08-07:
How important is keying?

securelyfitz, 2020-08-07:
The purpose of shroud is either keying or protecting pins. since the board already has a ton of vertical pins, i think the protection part is minimal - so we're just doing it for keying.

The question is how important keying is. It's a great convenience, but LA and SWD are the two connectors *I* use least.

- Neither connector has a dangerous VCC/GND disaster waiting to happen by rotating wrong - while the SPI connector does, and we don't shroud that
- Samtec options add $$ for the least used connectors -

I think if the choice is $amtec connectors or un-shrouded, we should go with un-shrouded. If there's a cheaper shrouded option with minimal redesign, i'd consider it.

Perhaps we should plan on unshrouded, then shrouded could be a crowdsupply stretch goal?

fharding1, 2020-08-07:
That sounds good to me. I can play around with switching to the shrouded header when I make the other changes. Is it normal to have tiers like that on crowdsupply?

securelyfitz, 2020-08-07:
it'd normally be a stretch goal, like "if we hit 500 preorders or $x, then we'll upgrade all boards to have shrouded swd connectors"

All that said, i'm still dwelling on:
> Neither connector has a dangerous VCC/GND disaster waiting to happen by rotating wrong - while the SPI connector does, and we don't shroud that

which is making me thing we should stop worrying, use unshrouded, and document part numbers for those who want to mod their own.

fharding1, 2020-08-07:
Fine with me!

securelyfitz, 2020-08-07:
Update: Found 10-pin connectors for $0.175 and 14-pin for $0.235 in full reels on alibaba. Working on securing them.

https://www.alibaba.com/product-detail/1-27mm-pitch-SMT-shrouded-header_60682653524.html

Let's keep design as-is, use these, and recommend unshrouded for people looking to build their own but reduce cost. If the alibaba connectors don't end up happening, then we can choose samtec or unshrouded in the future as costs allow. Closing issue.

Closed 2020-08-07.

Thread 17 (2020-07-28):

source a qwiic/stemma qt compatible connector

securelyfitz, 2020-07-28:
"JST SH 4 Pin (1.0mm pitch)"

JST part BM04B-SRSS-TB (vertical) or SM04B-SRSS-TB (right angle)

Perhaps there's a cheaper compatible one?

fharding1, 2020-07-31:
$0.09/PCS at quantity 100+

https://lcsc.com/product-detail/Wire-To-Board-Wire-To-Wire-Connector_JST-Sales-America-SM04B-SRSS-TB-LF-SN_C160404.html

Closed 2020-07-31.

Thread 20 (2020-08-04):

VTGT indicator remains lit without Vref applied when data out pins are hot

securelyfitz, 2020-08-04:
Initial observation::
Connect tigard, LA cable, and bitmagic with Vtgt off: VTGT indicator off. Vref = 0.3v
Slide switch to 1.8v: VTGT indicator on. Vref=1.8V
Slide switch back to VTGT: VTGT Indicator on (but should be off). Vref=1.0V
Disconnect bitmagic (from usb, or disconnect LA cable): VTGT indicator off. Vref=0.0V

Theory:
current is leaking through the level shifters back to Vref.

Experiment:
- attach steady 3.3v to a pin and measure Vref.
- measure Vref: 0.3V
- slide switch to 1.8v. Vref=3.3v
- slide switch back to VTGT: Vref=3.3v

all output buffer pins affected. No input buffer pins affected.

Implication:
if vref=vtgt, voltage on an output pin could leak through to vref, powering all tigard output pins, interfering with the target.

Resoluttion:
SN74LVC8T245 datasheet section 13.2:
"Keep /OE high until VCCA and VCCB are powered up"

VCCA is taken care of by FT2232H's /ENABLE
VCCB = Vref.

Right now:
/OE = /ENABLE
Fix:
/OE = /ENABLE or !Vref

I haven't come up with a magic fix without an extra component:
can't use the level shifters cause we're controlling them
can't use the spare sw1 poles cause that won't work w/ vtarget

securelyfitz, 2020-08-05:
Workaround for test purposes: powering tigard from a USB power supply without data lines will power on tigard and level shifters, but not trigger /enable, keeping the level shifters in high-z mode.

fharding1, 2020-08-06:
Can we do something like this (with an extra MOSFET)?

/ENABLE is HIGH, VREF is LOW (FTDI has not booted, no VREF): /OE is HIGH, therefore level shifter is OFF.
/ENABLE is LOW, VREF is LOW (FTDI has booted, no VREF): /OE is HIGH, therefore level shifter is OFF.
/ENABLE is LOW, VREF is HIGH (FTDI has booted, we have a VREF): /OE is LOW therefore level shifter is ON.
/ENABLE is HIGH, VREF is HIGH (FTDI has not booted, we have a VREF): /OE is HIGH therefore level shifter is OFF.

https://www.falstad.com/circuit/circuitjs.html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

securelyfitz, 2020-08-07:
Logic checks out. My analog skills are too rusty to even think of second guessing the simulation.

fharding1, 2020-08-07:
I'm a little concerned that you measured 300mV on VREF, considering the BSH103 has a very low Vgs(th) of 400mV, but considering there don't seem to be any more issues with the VTGT LED lighting up when you touch a VTGT pin anymore, I think we should be safe after adding one or two more VREF pull-downs to keep it safely below Vgs(th).

I have all the components to prototype this on a Tigard, so I can give it a try too.

securelyfitz, 2020-08-07:
tested again and measured 130mv, not 300mv. Don't know if that was a typo or other conditions changed. Same behavior whether i connect to computer USB (with day, /enable asserted, VTGT LED off, level shifter undefined) as to a usb battery(no data, /enable deasserted, VTGT LED off, level shifter tristated)

Will be interesting to see if prototype results yeild something different.

fharding1, 2020-08-08:
Even with /OE shorted to 3.3v current can leak from an output pin such as TDO back to VREF. So it appears the level shifter does not go true high-z with it's output disabled, contrary to the datasheet. I guess this means I'm missing something.

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

fharding1, 2020-08-09:
Actual issue: because current can flow from the output to VREF when the level shifter output is enabled, the level shifter output enable signal latches high.

* With mode switch at 1v8, apply voltage to an output pin. **Since /OE is low and the level shifter is not high-z, current starts flowing from the output to VREF**
* Flip the mode switch to VTGT. The LED stays lit despite removing the 1v8 buck power, because current is still flowing from the output to VREF, keeping the level shifter high-z and "latching" VREF
* Manually forcing /OE high turns the LED off, and it stays off, even if the output pin remains hot.

Resolution:

Documentation. Maybe look into an ideal diode solution in the future or something like that. No easy solution.

Closed 2020-08-09.

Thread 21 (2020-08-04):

Connect LA header's GND pins to GND

securelyfitz, 2020-08-04:
Working on a possibly related issue and discovered this, i assume they should be grounded.

however, let's capture it here if there's a reason they're not.

fharding1, 2020-08-05:
@securelyfitz oh, that's a really stupid mistake on my part. It's specified clearly in the BMB schematic. Will fix.

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

Closed 2020-08-07.

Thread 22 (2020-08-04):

Clarify LA port's capabilites in documentation

securelyfitz, 2020-08-04:
Optimistically, you could connect a logic analyzer to the LA port, then use Tigard as just an mechanical adapter.

Realistically, any load on testpoints affects signal integrity. Connecting a clip to a wire to tigard, which connects to 4 other pins and a level shifter, which connects to a LA harness, which connects to a LA is really a big load.

I'm opening this issue to discuss how to document this expectation, as well as have a record for those looking for more details.

Possible wording:

> The LA port is best suited to monitoring push-pull signals where Tigard is an intended driver or receiver. It's tested and working well with UART, SPI and JTAG, and generally works with I2C. The expected use case is that you are using Tigard to communicate with a target, but need to debug that communication.
>
> The LA port *may* be used as a passive mechanical adapter although this usage is not supported. For best results, power the Tigard board but disconnect VTGT from the target. Additional effort will likely be required to ensure signal integrity

fharding1, 2020-08-06:
Yeah to be honest I thought this might be a possible issue. I think how you worded it makes sense.

securelyfitz, 2020-08-06:
Sounds good. added to readme with 5075a9f2f9f69aa7f01e8a4ac6b9179c88f21eaa

Closed 2020-08-06.

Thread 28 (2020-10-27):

LA and SPI headers (j6 and j4) are too close to be used by IDC-style cables at the same time.

securelyfitz, 2020-10-27:
V0.1 had them far enough apart for typical IDC cables to be edge-to-edge, V1.0 shifted them over 1.5mm to make room for the stemma/qwiic connector.

Temporary Workarounds:

1. Use the JTAG connector for spi/i2c when you want to observe
2. or use individually crimped style instead of IDC-style connectors on the spi/i2c header
3. reinforce with superglue, then clip 1.5mm off the edge of the 14-pin LA connector so that it fits but stays in one piece

Solution:
Shift it back over 1.5mm left for next revision. Not sure if this warrants a major revision. physical layout will change but pinouts will not.

fharding1, 2020-10-28:
I don't think this necessitates a major rev either. I would consider moving one of the 2.54mm headers a major breaking change (since we have a test jig and people might make custom boards to access those pins), but not the LA header.

Closed 2020-12-09.

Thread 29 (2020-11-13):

Adding ZIF Socket for TSOP-48 NAND Dumping

whid-injector, 2020-11-13:
Aloha there!
Considering that some months ago I have started working on something similar to Tigard (i.e. called Piadinaboard that is the natural evolution of two previous board I worked on #Focaccia-Board and #Burtleina-Board [1][2]) and as soon as my new baby daughter will allow me to complete it... I will release it in opensource anyway... I don't see the reason to keep this thought for myself only. 😃 Especially because I really like your FOSS approach ❤️

In my FT2232H based board, beside level shifters and various pinouts for the supported protocols (i.e. SPI, JTAG, UART, SWD)... I have also added a ZIF socket in order to attach TSOP-48 NANDs.

The FT2232H works perfectly for dumping NANDs by using tools like nand-dump-tool or yand.

I feel like Tigard without this feature is kinda missing a key factor* that will easily allow hw hackers to dump NANDS without messing with the classic FT2232H breakout boards + tons of Dupont wires.... or some expensive Programmer like Dataman/RT809H/etc.

*Don't read me wrong. I am not saying Tigard is not cool. The opposite. What I am suggesting is something like... Imagine a juicy triple cheesburger missing two slices of crunchy bacon. Well... the ZIF socket to allow NAND Dumping is the bacon. 🤣

[1] https://github.com/whid-injector/Focaccia-Board
[2] https://github.com/whid-injector/Burtleina-Board

securelyfitz, 2020-11-13:
Aloha amico!

We thought a bit about how to add that capability, but decided it'd add too much cost and complexity for only a single use case.

Solid, reliable level shifting was a top priority for Tigard. We use all the level shifters in unidirectional mode, which works well for the protocols we end up using, but makes a mess when you start getting too fancy with custom bit banging options - we can't even swap port A and port B for UART/JTAG with our implementation.

In the end, we opted to go for better, easier support for the simpler interfaces versus the cost and size of adding more level shifters and switch logic that might get NAND support. I'll look forward to getting my hands on a Piadinaboard!

ciao!

whid-injector, 2020-11-14:
Yeah, I was just looking at your schematics and totally agree that with those unidirectional buffers doing bitbanging VS a NAND will be a PITA.
Well... let's say that a juicy triple cheeseburger is already tasty enough 🍔 ❤️  😄

securelyfitz, 2020-11-16:
nothing wrong with ordering a side of bacon. :)

Closed 2020-11-13.

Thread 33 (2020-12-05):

AVRDUDE Configuration?

Matir, 2020-12-05:
To use Tigard with avrdude, a small avrdude.conf is necessary:

```
programmer
  parent "avrftdi"
  id = "tigard";
  desc = "Tigard interface board";
  usbdev = "B";
  sck = 0;
  mosi = 1;
  miso = 2;
  reset = 5;
;
```

(Strictly speaking, the sck, mosi, and miso lines are not necessary as they are the same as the parent device.)

This configures it to use port B on the FT2232, and uses sRST for the reset line.

I'm happy to send a PR if you think including this in the repo would be useful, and if you can tell me if it should be in the root (I don't think so) or what such a directory might be named.  I also have an OpenOCD config I can contribute after some more testing.

securelyfitz, 2020-12-07:
Awesome!
This is something i knew *should* be possible but just haven't had the time to figure out if the software existed.

I've been meaning to figure out a plan for organizing the documentation and keeping track of common config files. It probably makes sense to just have a directory full of all of them, but there's probably a good argument to having that in a separate repository too - i'm not sure.

I have several other doc edits in progress, will be pushing them soon. Can make this at the same time.

thanks!

Matir, 2020-12-07:
If it helps, this should be used with avrdude like this: `avrdude -C +tigard.conf` This causes avrdude to first read the system configs (which gives the definition of all the chips, as well as the parent "avrftdi" programmer), then read this one.

I've now programmed a dozen times or more using this config and it just works.  (AVR ISP is basically SPI, so no big surprise there.)

securelyfitz, 2021-03-24:
finally added this in e02208ca971daef9f25430be8d94606f7fdcc4f4. Thanks for making it work! Will add tigard.conf with #36

Closed 2021-03-24.

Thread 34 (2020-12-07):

BOM has wrong LCSC Part Number for LA Header

Matir, 2020-12-07:
The part numbers embedded in the KiCad schematic for the LA header do not match.  The 14-pin Samtec header is correct (FTSH-107-01-F-DV-K) but the LCSC Part Number (C448647) is for the 10 pin version (which is used for the SWD connector).

I can't find a matching LCSC part number, so maybe it needs to removed entirely?  (Or maybe you know the part number and I just can't use lcsc.com correctly.)

fharding1, 2020-12-07:
Removing it seems like the right choice to me. I created a commit in the move-la-misc branch that should close this issue when merged into master.

Closed 2020-12-09.

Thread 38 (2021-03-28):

Hardware connector details in Readme.md

hattesen, 2021-03-28:
The readme.md is very well written and provides virtually all the information that is required to use the various interfaces, it is a sign of the high level of professionalism of this project, where many other similar projects fall short.

One piece of information that I would like to see added is a reference to the physical connector matching each hardware interface (pitch, pins, rows and a connector part number), especially for the non-0.1" pin headers like the [I2C connector](https://github.com/tigard-tools/tigard#i2c), possibly including full specs (both connectors and wiring) for frequently used wiring harness. This will make it easier to locate suitable harnesses/cables or find the parts to make them up.

On a side-note, the details of each interface should probably be moved out of readme.md and into separate interface.md pages, to make the readme.md more manageable, as it is likely to continue to grow over time.

securelyfitz, 2021-04-01:
Thanks! glad you found the readme useful.

I agree, mechanical specs would be really useful. I'll add them.

I started issue #37 to capture some of the pros and cons of keeping a flat readme vs breaking it out.

skochinsky, 2021-04-14:
+1
My cables arrived with some wires popping out of the connectors so it would be nice to know the "canonical" layout to put them back in proper order (yes I know I can track it back from the pinout but...)

securelyfitz, 2021-04-14:
@skochinsky The UART cable came with only VTGT, GND, TX and RX attached since these are what's used 99% of the time. Loose DTR, RTS, etc wires were included in case you wanted to use them, but not assembled to keep the uart wiring harness easier to use for the common case.

Right now the pinouts are listed [further below in the readme](https://github.com/tigard-tools/tigard#uart-1) and will likely be moved up into a single UART section in the refactoring for #37

skochinsky, 2021-04-15:
Thank for the explanation!

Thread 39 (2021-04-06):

Understanding LA

Kabron287, 2021-04-06:
According you explanations and schematic LA has 8 channels xPB0-xPB7.
Actually, only 4 channels really works with Sigrok Pulseview:
UART_RX-AD1
UART_CTS-AD3
UART_DSR-AD5
UART_DCD-AD6
In theory two more signals could be used:
BD2, BD6
And that is all, because rest of the signals are not inputs and could not be switched to inputs.
So, as long as PulseView is the only suitable SW, LA is 4 channels width.

Or, I do not understand something?
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

securelyfitz, 2021-04-06:
The logic analyzer port isn't there to use tigard as a logic analyzer, it's there to use a logic analyzer to inspect the communication between Tigard and your target system.

See the [I2C example](https://learn.securinghardware.com/lessons/i2c/) - if you were working with an I2C device but were having trouble getting a response from the target device, or were getting unexpected/invalid/corrupt data, you could attach the logic analyzer and then examine the i2c protocol and perhaps identify timing or signal strength issues.

Let me know if there's anywhere in the documentation where I could to clarify this to avoid misrepresenting Tigard as a logic analyzer itself. Yes, there is an MPSSE logic analyzer driver in pulseview, but my experience with it has been frustrating at best.

Kabron287, 2021-04-06:
Thanks for answer.
>>Let me know if there's anywhere in the documentation where I could to clarify this to avoid misrepresenting >>Tigard as a logic analyzer itself.
Obviously - nowhere, but my question is an example of this.

I guess, it could be stated out, say in form you answer me:
The logic analyzer port isn't there to use tigard as a logic analyzer, it's there to use **another** logic analyzer to inspect the communication between Tigard and your target system.

securelyfitz, 2021-04-06:
revised the readme text in e1927e9951568c4fb76dfcf3dc6b9c09ee046816
Do you think the wording is more clear now?

The MPSSE logic analyzer driver appears to work nicely, but my experience is that the timing and data rate has LOTS of jitter, making signals not come out anything like expected. Ideally there should be a better clock source on an FT2232H intended for logic analyzer usage - though that might be doable on the existing headers and may require some firmware...

Kabron287, 2021-04-06:
Crystal clear

securelyfitz, 2021-04-07:
great. You're not the first to ask a similar question, so glad to get it documented clearly.

Closed 2021-04-07.

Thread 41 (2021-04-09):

Unable to get UrJTAG to work with Tigard

skullhornet, 2021-04-09:
I have an existing setup where I am using the Olimex ARM-USB-TINY-H, it contains the same FTDI device as Tigard the: 2232H

From Urjtag I specify the following cable:

jtag>cable FT2232 vid=0x15BA pid=0x002A driver=ftd2xx-mpsse interface=0

To use it with Tigard I set the voltage switch reference to 3V3, change the VID/PIDs and the interface number.

jtag>cable FT2232 vid=0x403 pid=0x6010 driver=ftd2xx-mpsse interface=1

However when I run the 'detect' command no chain is detected. Needless to say it works perfectly with the ARM-USB-TINY-H.

securelyfitz, 2021-04-12:
Thanks for reporting. Was able to (partially?) recreate.

I didn't need to define driver=, but there seems to be a bug in urjtag - by default the frequency is set to 6MHz, but is going much faster than that - too fast to get a result for detect or discovery.

Try this:

```
jtag> cable ft2232 vid=0x403 pid=0x6010 interface=1
Connected to libftdi driver.
jtag> frequency 100000
Setting TCK frequency to 100000 Hz
jtag> detect
IR length: 5
Chain length: 1
Device ID: 00010110001101010010001001001111 (0x1635224F)
  Unknown manufacturer! (00100100111) (/usr/share/urjtag/MANUFACTURERS)
jtag>
```

While this works for me, It should set tck to 100khz, but my logic analyzer shows it is actually running tck at 500kHz.

I updated the readme with this info, Let me know if this doesn't work for you.

skullhornet, 2021-04-12:
Thank you for looking into this. Using your instructions I was able to get a proper detect.

skullhornet, 2021-04-13:
I just compiled the latest version of UrJTAG (2021.03) and things look like they are done properly now. I think it's the precompiled versions/upstream which have this error. I attached a capture from my Salea using the new software which produces a .sal file. There is only one channel: TCK. If you don't own a Salea you can install the software and take a look at the capture without the hardware device.

[tigard_tck.zip](https://github.com/tigard-tools/tigard/files/6305024/tigard_tck.zip)

Closed 2021-04-12.

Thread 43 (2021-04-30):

USB String

UweBonnes, 2021-04-30:
Hello,

does tigrad put some string in the usb descriptors so that it can be recognized?. That string is very helpfull with automatic device detection.

securelyfitz, 2021-04-30:
you should see manufacturer, produc, and serial in the usb descriptor:
```[523710.719667] usb 1-1.2.3: new high-speed USB device number 101 using xhci_hcd
[523710.830827] usb 1-1.2.3: New USB device found, idVendor=0403, idProduct=6010, bcdDevice= 7.00
[523710.830831] usb 1-1.2.3: New USB device strings: Mfr=1, Product=2, SerialNumber=3
[523710.830834] usb 1-1.2.3: Product: Tigard V1.0
[523710.830836] usb 1-1.2.3: Manufacturer: SecuringHardware.com
[523710.830837] usb 1-1.2.3: SerialNumber: TG1000160
[523710.855758] usbcore: registered new interface driver usbserial_generic
```
```
Device Descriptor:
  bLength                18
  bDescriptorType         1
  bcdUSB               2.00
  bDeviceClass            0
  bDeviceSubClass         0
  bDeviceProtocol         0
  bMaxPacketSize0        64
  idVendor           0x0403 Future Technology Devices International, Ltd
  idProduct          0x6010 FT2232C/D/H Dual UART/FIFO IC
  bcdDevice            7.00
  iManufacturer           1 SecuringHardware.com
  iProduct                2 Tigard V1.0
  iSerial                 3 TG1000160
  bNumConfigurations      1
```

UweBonnes, 2021-04-30:
With the definitions you gave and the schematic, I tried to add the tigard definition to blackmagic. Please checkout my fixes branch and compile "blackmagic PROBE_HOST=hosted. Running with the mode-switch set to JTAG , "blackmagic -t" should scan for JTAG and print the found devices. In the SWD setting  "blackmagic -e" should do a jtag scan. '-e" stands for "external resistor". Feedback welcome!

Closed 2021-04-30.

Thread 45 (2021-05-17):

Pinout detection-discovering

skaox, 2021-05-17:
Hello,

is it possible to detect-discover pinout (UART, JTAG, SPI, I2C), fuzzing and command enumeration like [Busside](http://wiki.infosectcbr.com.au/index.php/Busside) ?

Thank you in advance

securelyfitz, 2021-05-17:
Detect/discover: no
spi fuzzing/command enumeration: yes, but not implemented
i2c address detection: yes, with PyFTDI
jtag command enumeration: yes, with URJTAG and other tools

Unfortunately, detect/discover is not really feasibe.
Detection algorithms depend on algorithms that try different combinations of inputs an outputs. In order to ensure Tigard's normal operation was exceptionally robust, we used unidrectional level shifters, meaning we cant change inputs to outputs and vice versa.
Busside doesn't have the same degree of level shifting and i/o protection as tigard, but is very flexible in how it uses pins. the JTAGulator does have significant I/O protection, but that comes at a much higher cost, and does lead to issues with some specific JTAG targets not working in 'jtag adapter' mode

There's no reason that command searching couldn't be implemented for SPI, I'm just not aware of an implementation. If i were to, i would implement it using PyFTDI.
PyFTDI does include a script to detect properly-wired I2C devices. URJTAG includes a 'discovery' command that will detect the length of all the data registers, helpful in determining their purpose.

skaox, 2021-05-17:
Noted ; a big THANK YOU for the answer and what you're doing.

Closed 2021-05-17.

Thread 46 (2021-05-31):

UART mode problem

sidprice, 2021-05-31:
Just fired up my Tigard for the first time (was a Crowd Supply backer) to use the UART feature and it does not appear to be working.

I am using Windows 10 and in Device Manager I see two COM ports. I have connected my terminal emulator to the first one (COM35) and it is set up for 115,200, 8N1 and no handshake.

Tigard is not connected to the target PCB, it is set to use internal power. When I press keys in the terminal I do not see any LED flashes and a scope on the TX pin shows it remains in a high state.

I think I have the set up right, but since this is a first use I could be mistaken.
Sid

Droid-MAX, 2021-05-31:
try another ports？

sidprice, 2021-05-31:
I tried another serial adapter and it works, Tigard does not.

fharding1, 2021-05-31:
The FT2232H exposes two serial ports to your computer. Only one is used on Tigard. You mention trying the first COM port, have you tried the other?

On my (Linux) computer, /dev/ttyUSB0 is the correct one to use, while /dev/ttyUSB1 does nothing.

sidprice, 2021-05-31:
I tried both COM ports, the TX LED never flashes.

fharding1, 2021-06-01:
Perhaps it's a [driver issue](https://learn.adafruit.com/adafruit-ft232h-breakout/serial-uart)? You might try on an OS X or Linux computer if you have one available. I believe every unit was loopback tested, so it would be very unlikely that you got a dud (but not impossible).

securelyfitz, 2021-06-01:
1. Have you installed ftdi drivers?
2. Are you sure you're talking to the right com port? (only the primary port can be used for UART)
3. What terminal emulator are you using?
4. What serial adapter *does* work?
5. Does it work for JTAG/SPI/ETC?
6. Does it work on a linux/osx system?

See the screenshot below, i chose the first com port of the composite device, and was able to connect with putty:
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

sidprice, 2021-06-01:
Thanks for the pointers - drivers are installed:

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

Yes I am sure I am using the right serial ports.

I am using SecureCRT from Van Dyke Software.

I have not tested other modes.

I do not have a Linux or OSX computer.

The issue is that the TX LED never flashes, regardless of connection to the target or power mode.

Terminal connection to my target works fine with AdaFruit CP2104 Friend, I have several and they all work fine.

securelyfitz, 2021-06-01:
Are all three LEDs - PWR, EN, and VTGT - all lit up?

If you 'view devices by connection' you can confirm that you're using the com port associated with port A.

CP2104 has a silicon labs chip which means it doesn't rule out driver issues.

can you try using putty to rule out software issues?

can you try using jtag or spi or i2c to rule out hardware issues?

sidprice, 2021-06-01:
>>> Are all three LEDs - PWR, EN, and VTGT - all lit up?
Yes

>>> If you 'view devices by connection' you can confirm that you're using the com port associated with port A.

Yes, confirmed.

>>> can you try using putty to rule out software issues?

Seems that is the problem. If I use putty the TX LED flashes.

I have no idea why SecureCRT doesn't work the same.

securelyfitz, 2021-06-01:
thanks for testing. It's possible there's multiple different layers of API access to the serial ports in windows, and whichever one SecureCRT is using is the issue?

Let me know if you have any additional issues.

Closed 2021-06-01.

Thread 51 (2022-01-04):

SWD config holds nRF in reset making debugging impossible

littlelailo, 2022-01-04:
Disclaimer:
I'm new to HW stuff so maybe this is sth completely obvious to anyone except for me, but it cost me two days to figure out so I thought I should share it here.

I tried to debug an nRF Dev Board over the P18 header using the tigard and I kept getting a "poll 4 timeout" Error during the init sequence in openocd. The reason why this happens is that the openocd config holds the nRF in reset and so it's not responding leading to OCD erroring out.

The solution is pretty simple:
Change `ftdi_layout_init 0x0018 0x05fb` to `ftdi_layout_init 0x0018 0x055b` in the init file to not pull up the reset pin during init. And after that everything works (also reseting the board via telnet works, so I don't think I broke anything, just changed the initial value of the pin)
(As a sidenote I think the config file is out of date, it should be `ftdi layout_init` instead of `ftdi_layout_init` - I got a couple of DEPRECATED warnings before changing that)

And I have to say: Thanks for providing such an awesome tool, it really helps me with my project!

securelyfitz, 2022-01-04:
Good catch. I had mostly been testing and using it with the JTAG harness and only connecting VTGT, GND, SWCLK, and SWDIO - leaving reset disconnected. Fixed in 6f935c497fd831a3b53ff4480f017a005695ca4d

What version of openocd are you using? The config files were originally made before v10. I've hesitated to fix the depricated parts without testing against a few older versions of openocd - i'd prefer to have one config file that works against V9-11 and throws deprecation warnings than a separate file for each version. I know i'll have to fix it sooner or later, so i'll keep this issue open.

Glad you're finding tigard useful!!

littlelailo, 2022-01-04:
I'm using v11 (commit from late Dec)

And yeah I also tried to only do it like this (VTGT, GND, SWCLK and SWDIO) using jumper but for some reason that's not working at all (only have success when connecting over the P18 debug header). If you have any ideas on how to debug this I would also immensly appreciate it cause the real target doesn't have a 10 pin header (it's an AirTag)

securelyfitz, 2022-01-04:
I haven't used more recent nordic dev boards, but iirc some of the older ones detected the presence of the debugger and disabled/disconnected the built-in debugger when attached. Could that be it?

littlelailo, 2022-01-05:
I mean it works over P18 and I don't see detecting logic on the [schematics](https://www.nordicsemi.com/-/media/Software-and-other-downloads/Dev-Kits/nRF52-DK/nRF52-Development-Kit---Hardware-files-2_1_1.zip) (PCA10040_Schematic_And_PCB.pdf)...

For me it seems like the nRF struggles to pull the SWDIO line low (first one is over P18 second one is using jumpers):
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
With that in mind I connected the jumpers and then tried to find a difference by measuring resistance between the two cortex headers (cause in theory all pins should be connected with 0 Ohm if my jumper connections are right). The only difference I found between the jumpers and the cable connection is that if I measure SWDIO on the P18 to the cortex header on the tigard I get 330 Ohm (R16 - tigard schematics) which is bypassed when I use the cable connection instead of the jumpers but I don't see how that could result in such a problem... (but then again I'm new to HW so maybe that's actually the issue?)
I would love to break out the cortex header directly and then connect the pins 1 by 1 but unfortunately I don't have a 1.25 mm to 2.54 mm board or cables that fit into the small pins

securelyfitz, 2022-01-12:
Closing this because the original issue, the SWD config, is resolved.
Opening #52 to address the SWDIO-on-2.54mm-header issue and #53 to address the I2C 'hack' implications

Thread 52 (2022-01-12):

SWDIO not directly accessible on JTAG header

securelyfitz, 2022-01-12:
The 8-pin 2.5mm JTAG header has the TDI pin labeled as SWDIO.

Issue #51 identified that this isn't working as intended. While this does work in some cases, but is not ideal because it is tied directly to the always-on always-output level shifter, and only tied to the input through the 330 ohm resistor. The target has to drive SWDIO very strongly to have it's signal heard.

Workaround 1: Always use the cortex header whenever possible for SWD
Workaround 2: choosing a lower voltage on the VTGT switch might make it easier for the target to 'overcome' the level shifter's output

The solution to this is hardware redesign, perhaps using a 3-pole switch to swap SWDIO and TDO on all the auxiliary headers. This might benefit I2C as well. Since SWD and I2C are lower-prioirity interfaces, this is unfortunately a low priority.

ikarus23, 2022-03-29:
Hi. It is probably best to update the documentation (the main `README.md`) until this is fixed. I've run into the same issue because the readme still sates "You can also use the TCK(for SWCLK) and TDI(for SWDIO) pins of the JTAG header" as if there were no difference.

PS: Thank you for this amazing and well documented tool!

securelyfitz, 2022-03-30:
Good catch, thanks @ikarus23. I removed one other reference but missed that one. Glad the documentation is helpful to you!

XMPPwocky, 2023-08-02:
For existing Tigards, there's a pretty straightforwards hack to at least get SWDIO exposed on an ordinary 0.1" header- use the (header pin unpopulated, at least on my Tigard) ICE_CDONE pin (labeled "??" in silk-screen) on the JTAG header. Cut the trace between it and the level shifter, and then reconnect it with a bodgewire to pin 2 on the Cortex debug header. Now you should be able to use the "??" pin on the JTAG header as SWDIO.

securelyfitz, 2023-08-02:
@XMPPwocky nice workaround! the pin isn't populated since the ice40 programming is such a niche feature, and because then the JTAG and UART headers are different pin counts.

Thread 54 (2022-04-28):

Incorrect signal configuration for OpenOCD

tchebb, 2022-04-28:
I'm confused about the following bit of the OpenOCD configuration in the README:
```
ftdi_layout_init 0x0078 0x017b
ftdi_layout_signal nTRST -ndata 0x0010 -noe 0x0040
ftdi_layout_signal nSRST -ndata 0x0020 -noe 0x0040
```

Comparing this to the v1.1 schematic, there seem to be several inconsistencies:
 1. The data direction bitmask (`0x017b`) sets BD6 and BC0 as outputs, even though BD6 is connected to the input buffer (and not used for JTAG) and BC0 is unconnected exactly like BC1-7, which are all set as inputs.
 2. The nTRST and nSRST signals use BD6 as an output enable (which OpenOCD uses to tristate the pins), but that pin isn't connected to the output buffer at all. In reality, the nTRST and nSRST signals are not tristatable because we keep the output buffer enabled at all times.
 3. The nTRST and nSRST signals use `-ndata` instead of `-data`, meaning OpenOCD inverts the signals it puts on the pins. The signals are not inverted in hardware, though, meaning that asserting either of these signals brings it high instead of low. I've verified that this is the case with my Tigard.

Is there something I'm missing? I'd expect the config to look like this, given Tigard's shipping hardware:
```
ftdi_layout_init 0x0038 0x003b
ftdi_layout_signal nTRST -data 0x0010
ftdi_layout_signal nSRST -data 0x0020
```

securelyfitz, 2022-04-28:
Thanks for noticing this.
The openocd config is derived from the one i've been using for years with various ftdi boards, sometimes with additional hardware and sometimes without. One used BD6 as an enable on a level shifter.
I need to check on point 3 though - I use several devices with nTRST that shouldn't be working at all if the signal was inverted, but the do seem to work. I'll check those out and update the readme once i confirm what's happening.

tchebb, 2022-04-29:
FYI, I've posted a draft change for upstream OpenOCD to add a config file for Tigard: https://review.openocd.org/c/openocd/+/6952. I wrote this config from scratch based on the schematics, but it's pretty similar to the one in the README save for the signal layout. I'll wait until you're done investigating on your end to mark it as ready for review, though.

securelyfitz, 2022-05-02:
Thanks for your patience.
I have a couple targets that use the nTRST signal and work fine with tigard's existing (flawed) config file. Observing on a scope, i understand why. The board config files i'm using don't include any direct control of ntrst or nsrst - which means openocd leaves them high with either tigard config file.

On one device I have that pulls nTRST low, openocd leaves it high, which 'enables' jtag on that target. By default openocd uses tms/tck reset, so everything works fine.

On another device, while i have nSRST wired, openocd is using a jtag-command-triggered reset instead of the nSRST signal.

So 1) the changes you propose are correct 2) they don't break any of the boards i'm typically using 3) but that's because i'm not using board config files in a way that actually uses the reset signals.

Question for you - where do you think the best place is for the transport select command? I see a mix of board, target, and interface files all setting it. Right now, i direct people to have separate interface config files, since most of my use cases are bringing up a board before a board file is available...

tchebb, 2022-05-03:
> Question for you - where do you think the best place is for the transport select command?

I've never been too sure of this myself either. Like you say, the upstream files are inconsistent and OpenOCD's documentation doesn't give a clear answer either.

My personal habit is to leave transport and speed settings out of both the interface and the target configs. I either pass them on the command line between including the two files, or I make them part of a small, per-project "glue" file that includes everything needed.

I can see the argument for putting the transport with the target, though, especially for targets that support only a single kind of debug interface. I left it out of my Tigard config since Tigard can do both JTAG and SWD (although I haven't used SWD myself, so maybe it needs other config changes too).

securelyfitz, 2022-05-03:
looks like if you don't set it, it auto-selects 'jtag'. That means a generic tigard.cfg can leave it undefined and work in the majority of cases.

If someone is using SWD, they can define it in the board or target file, or use a specific tigard-swd.cfg

I did already adjust both the JTAG and SWD config in the readme in 4ac4998.

Thanks again for digging into this, and thanks for posting the openocd change - it's been on my todo list for.... two years?!

Seas0, 2022-06-01:
Current config seems still broken for SWD reset, as the reset pin is not initialized with output mode.
Also adding `reset_config trst_push_pull srst_push_pull` is necessary for a ftdi adapter without tri-state gate setup.

My configuration for reference:
```
adapter driver ftdi
transport select jtag
ftdi_vid_pid 0x0403 0x6010
ftdi_channel 1
ftdi_layout_init 0x0038 0x003b
ftdi_layout_signal nTRST -data 0x0010
ftdi_layout_signal nSRST -data 0x0020
reset_config trst_and_srst separate srst_nogate trst_push_pull srst_push_pull
```

securelyfitz, 2025-04-04:
New config files have been posted and working without complaints for a while now - closing this. Thanks everyone!

securelyfitz, 2025-04-04:
New config files have been posted and working without complaints for a while now - closing this. Thanks everyone!

securelyfitz, 2025-04-04:
New config files have been posted and working without complaints for a while now - closing this. Thanks everyone!

Closed 2025-04-04.

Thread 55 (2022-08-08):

JTAG : TDO seems to be stuck at 1

pirrup, 2022-08-08:
When i do detect in urjtag i get error about TDO stuck at 1 or 0

Any idea what the issue could be ? i checked TDO and no short with VCC or Ground

securelyfitz, 2022-08-09:
I need some more details about your setup to understand what's going on.
If you've got an error saying TDO is stuck, its typically a wiring issue. Is the error stuck at 1 or stuck at 0? If you short TDO to ground, does it change to zero and when you short it to VCC does it change to 1? If so - then your configuration is right, you just need to get your wiring correct to. If not- then it's time to examine your configuration.

Either way - let me know more about your setup - what version of what tools, what commands you're running, and what your wiring setup to your target is. Then i might be able to spot a mistake, or if not recreate your setup to see what's going on.

pirrup, 2022-08-16:
jtag> cable ft2232 vid=0x403 pid=0x6010 interface=1
Connected to libftdi driver.
jtag> frequency 100000
Setting TCK frequency to 100000 Hz
jtag> detect

when tigard is set to VTGT (no power to target) and do detect response is: TDO seems to be stuck at 1
when tigard is set to VTGT (with power to target) and do detect response is: TDO seems to be stuck at 1

when tigard is set to 1.8 (so VCC comes from tigard)  and do detect response is: TDO seems to be stuck at 0

using latest urjtag on ubuntu

wiring :
TCK -> TCK
TRST -> TRST
TDO -> TDO
GND -> GND
TMS -> TMS
TDI -.> TDI
VTGT -> VREF 1.8

securelyfitz, 2022-08-16:
Nothing jumps out at me to try, so a few more questions to understand the situation:
What's the status of the 3 leds in each of those scenarios? https://github.com/tigard-tools/tigard#debugging

What happens in scenario 1 or 2 when you take the tigard TDO wire and short it to ground?
What happens in scenario 3 when you short TDO to VTGT?
How much power is the target consuming on the 1.8v VTGT in scenario 3? Can you check if the voltage with a multimeter?

Is the target confirmed working with another JTAG adapter?
Could you try using openocd with the same setup to see if you get the same behavior?

pirrup, 2022-08-17:
scenario 1 : no VTGT LED
scenario 2 : ALL LEDS WORKING
scenario 3 : ALL LEDS WORKING

short to ground :
scenario 1 : stuck at 1
scenario 2 : goes to stuck at 0

short to VTGT:
scenario 3 : goes to stuck at 1

power in scenario 3 is 1.77V

target i cannot disclose publicly , but can be discussed offline .

securelyfitz, 2022-08-17:
So, looking at all the pieces, you've got:
1. the tool, urjtag
2. the configuration within the tool for your interface
3. the usb communication to the controller
4. the controller (tigard)
5. the level shifting on the controller
6. the wiring to the target
7. the target itself

your tests completely rule out 2, 3, and 5, and partially cover 4 and 6.

The best bet now is to try one or all of the folllowing:
- use openocd to see if that identifies any idcode, ruling out a software issue
- use a different jtag adapter if you've got one, to rule out a bad tigard
- use a different jtag target, to rule out the target as an issue

iBringsTheRuckus, 2025-03-29:
I'm having this same exact issue. I'm trying to connect to a Xilinx XC3S50A FPGA via JTAG.
```
UrJTAG 2021.03 #
Copyright (C) 2002, 2003 ETC s.r.o.
Copyright (C) 2007, 2008, 2009 Kolja Waschk and the respective authors

UrJTAG is free software, covered by the GNU General Public License, and you are
welcome to change it and/or distribute copies of it under certain conditions.
There is absolutely no warranty for UrJTAG.

warning: UrJTAG may damage your hardware!
Type "quit" to exit, "help" for help.

jtag> cable ft2232 vid=0x403 pid=0x6010 interface=1
Connected to libftdi driver.
jtag> frequency 100000
Setting TCK frequency to 100000 Hz
jtag> detect
warning: TDO seems to be stuck at 0
```
I have it connected to TDI, TDO, TMS, TCK, and GND.
I have a VTGT connected via VCCAUX which is a solid 3.26v right off the FPGA. I have checked TDO as well as all the other pins and they are also 3.26v. So what does TDO seems to be stuck at 0 mean??
I've spent hours trying to figure out what's going wrong and haven't been able to connect via JTAG with urJTAG or OpenOCD. I'm slowly losing my mind over this.

I have also tried disconnecting VTGT and setting the switch on Tigard to 3.3v with the same exact outcome. I don't have another JTAG board to try, but I'm about to buy one to see if it's an issue with my tigard.

I do want to mention my Jtagulator does pick up TDI, TDO, TMS and TCK correctly and does give a device ID. Although it's incorrect. Talking with Joe, he had this to say about the device ID. "Yes, this is a normal response. The Device ID might not conform to the JTAG specification (the vendor can set it however they want)"

securelyfitz, 2025-03-29:
TDO stuck at 0 means that the TDO pin only ever sees 0v. It could mean that urjtag/openocd is looking at the wrong pin, or that the device isn't outputting anything, or that the tigard isn't connected to the jtag input pins properly, or the tigard isn't speaking jtag properly.

What happens when you try shorting TDO to vtgt? That should tell us if the software stuff is all up and running and talking to tigard properly.

iBringsTheRuckus, 2025-03-29:
I verified TDO definitely has 3.26v at boot and after boot. All the the required jtag pins have holes in the PCB where I soldered in connectors and the soldering is solid and so is the connection via jumpers to Tigard with the supplied jtag harness.

Just so I'm clear, you want me to short TDO to VTGT on Tigard itself and then run detect?

securelyfitz, 2025-03-29:
Where are you measuring tdo? If tigard sees 3.26v on the tdo pin, and your vtarget is somewhere around that, you should be getting told tdi is stuck at 1

Is the "JTAG-SPI/I2C-SWD" switch on tigard set to the left selecting jtag mode?

What i would expect to see is disconnecting the tdo wire from the target and connecting TDO (as in - Tigard's TDO pin, not the target's tdo) to ground would give you "tdo stuck at 0" and to vtgt should give you "tdo stuck at 1"

If it doesn't - you're either not talking to the right jtag interface, or your tigard is having electrical issues.

iBringsTheRuckus, 2025-03-29:
Tigard TDO to ground I get stuck at 0
Tigard TDO tied to VTGT I get stuck at 1

So before connecting Tigard I get 3.26v on TDI, TDO, TMS and TCK

When I connect Tigard and test voltages at the pins on the target device I lose the voltage on all TDI, TDO, TMS and TCK.

I'm honestly not sure what's going on at this point

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

securelyfitz, 2025-04-04:
do you have any other jtag target devices you could test your tigard on?

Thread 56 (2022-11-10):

Tigard stopped working with avrdude - all output pins stuck high?

jackw01, 2022-11-10:
I have successfully used Tigard with avrdude on Windows 11 to flash AVR microcontrollers in the past (last time about 5 months ago) and tried to do it again today, but it does not work. It appears that all the output pins are stuck high (at VTGT) and even the reset pin is never pulled down. I am wondering if this is a driver issue, the only thing that I've changed since it worked properly is installing Windows updates. Tigard currently shows up as two separate COM ports in device manager, both using the FTDI 2.12.36.4 driver.

The contents of `tigard.conf` are identical to what is suggested in the README.

```
C:\********>avrdude.exe -C +C:\********\tigard.conf -c tigard -vvv -p m88pb
executable_abspath = C:/********/avrdude.exe
executable_abspath_len = 39
executable_dirpath = C:/********
executable_dirpath_len = 27
sys_config = C:/********/avrdude.conf
sys_config_found = true

avrdude.exe: Version 6.99
             Copyright (c) Brian Dean, http://www.bdmicro.com/
             Copyright (c) Joerg Wunsch

             System wide configuration file is "C:/*********/avrdude.conf"
             Additional configuration file is "C:\********\tigard.conf"

             Using Port                    : usb
             Using Programmer              : tigard
I avrftdi_open(714): Using device VID:PID 0403:6010 and SN '(null)' on interface B.
D write_flush(479): Setting pin direction (0x0000) and value (0x0000)
I set_frequency(210): Using frequency: 150000
I set_frequency(211): Clock divisor: 0x0027
D avrftdi_check_pins_mpsse(571): Using valid mask mpsse: 0x0000fff8
D avrftdi_check_pins_bb(535): Using valid mask bitbanging: 0x0000ffff
I avrftdi_pin_setup(645): Pin direction mask: 002b
I avrftdi_pin_setup(646): Pin value mask: 0000
             AVR Part                      : ATmega88PB
             Chip Erase delay              : 9000 us
             PAGEL                         : PD7
             BS2                           : PC2
             RESET disposition             : dedicated
             RETRY pulse                   : SCK
             serial program mode           : yes
             parallel program mode         : yes
             Timeout                       : 200
             StabDelay                     : 100
             CmdexeDelay                   : 25
             SyncLoops                     : 32
             ByteDelay                     : 0
             PollIndex                     : 3
             PollValue                     : 0x53
             Memory Detail                 :

                                      Block Poll               Page                       Polled
               Memory Type Mode Delay Size  Indx Paged  Size   Size #Pages MinW  MaxW   ReadBack
               ----------- ---- ----- ----- ---- ------ ------ ---- ------ ----- ----- ---------
               eeprom        65    20     4    0 no        512    4      0  3600  3600 0xff 0xff
                                      Block Poll               Page                       Polled
               Memory Type Mode Delay Size  Indx Paged  Size   Size #Pages MinW  MaxW   ReadBack
               ----------- ---- ----- ----- ---- ------ ------ ---- ------ ----- ----- ---------
               flash         65     6    64    0 yes      8192   64    128  4500  4500 0xff 0xff
                                      Block Poll               Page                       Polled
               Memory Type Mode Delay Size  Indx Paged  Size   Size #Pages MinW  MaxW   ReadBack
               ----------- ---- ----- ----- ---- ------ ------ ---- ------ ----- ----- ---------
               lfuse          0     0     0    0 no          1    1      0  4500  4500 0x00 0x00
                                      Block Poll               Page                       Polled
               Memory Type Mode Delay Size  Indx Paged  Size   Size #Pages MinW  MaxW   ReadBack
               ----------- ---- ----- ----- ---- ------ ------ ---- ------ ----- ----- ---------
               hfuse          0     0     0    0 no          1    1      0  4500  4500 0x00 0x00
                                      Block Poll               Page                       Polled
               Memory Type Mode Delay Size  Indx Paged  Size   Size #Pages MinW  MaxW   ReadBack
               ----------- ---- ----- ----- ---- ------ ------ ---- ------ ----- ----- ---------
               efuse          0     0     0    0 no          1    1      0  4500  4500 0x00 0x00
                                      Block Poll               Page                       Polled
               Memory Type Mode Delay Size  Indx Paged  Size   Size #Pages MinW  MaxW   ReadBack
               ----------- ---- ----- ----- ---- ------ ------ ---- ------ ----- ----- ---------
               lock           0     0     0    0 no          1    1      0  4500  4500 0x00 0x00
                                      Block Poll               Page                       Polled
               Memory Type Mode Delay Size  Indx Paged  Size   Size #Pages MinW  MaxW   ReadBack
               ----------- ---- ----- ----- ---- ------ ------ ---- ------ ----- ----- ---------
               calibration    0     0     0    0 no          1    1      0     0     0 0x00 0x00
                                      Block Poll               Page                       Polled
               Memory Type Mode Delay Size  Indx Paged  Size   Size #Pages MinW  MaxW   ReadBack
               ----------- ---- ----- ----- ---- ------ ------ ---- ------ ----- ----- ---------
               signature      0     0     0    0 no          3    1      0     0     0 0x00 0x00

             Programmer Type : avrftdi
             Description     : Tigard interface board
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
jackw01, 2022-11-12:
I don't have a logic analyzer, but I was able to confirm that the SRST pin stays high when not connected to the target. I was able to program the target using an Arduino as ISP, so I don't think that's the issue. I tried changing the reset pin assignment in the tigard.conf file to each of the FT2232 pins connected to the output buffer and found that the only pins I could see a signal with are ADBUS0 (UART_TX) and ADBUS4 (UART_DTR), but not ADBUS2 (UART_RTS) or BDBUS0 through BDBUS5 for some reason.

I tried manually pulling down ADBUS2 and BDBUS0-BDBUS5 with a 10K resistor while monitoring each of the corresponding output pins, and was able to confirm this way that the output buffer IC is not the problem and that the FT2232 output pins themselves are not functioning as expected.

securelyfitz, 2022-11-14:
Ok, that's really odd behaviour. Some - but not all output pins are not properly outputting. It could be the FTDI, the level shifter itself, the pullpup resistor network in between them, or the pcb traces. Though -  it could still also be a software/configuration issue since you're still using only avrdude to debug.

The best piece of info right now would be to see if JTAG, SPI, I2C, or SWD work with a different program, like OpenOCD, Flashrom, or something else. If they do - it's probably an avrdude issue. If they don't - it's probably a hardware issue.

If it is really a hardware issue, the next thing i'd do is look carefully at the board to see if any traces or pads are scratched, shorted, or otherwise damaged. I'd use a multimeter to make sure RN1 and RN2 are showing 100k ohms.

jordiorlando, 2022-11-19:
Hey Joe, it's been a while! I'm seeing the same behavior on Windows 11 and have verified it using my BitMagic. I ran the following command on both Linux and Windows: `$ avrdude -C +tigard.conf -c tigard -p m32u4`. The tigard.conf file is exactly the same as the one in the README in this repo.

Linux logic analyzer capture:
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

Windows 11 logic analyzer capture using @mariusgreuel's AVRDUDE fork for Windows:
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

Windows 11 logic analyzer capture using stock AVRDUDE for Windows:
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

securelyfitz, 2022-11-21:
@jordiorlando thanks for checking it out. I dug up a windows laptop and tested @mariusgreuel's 6.x and 7.0 on W10 and both worked fine (after i spent too long debugging my ICSP cable plugged in backwards)
I don't have a w11 system to test on though - do either you or @jackw01 have a w10 system you could try? If not i can figure out how to get one up and running.

Thanks,
-joe

jackw01, 2022-11-22:
I don't have a Windows 10 system, but I can confirm that avrdude 6.99 worked on early 2022 builds of Windows 11.

jackw01, 2022-11-23:
I have the same issue with both 6.99 and 7 on my current Windows 11 build.

jordiorlando, 2022-11-24:
@securelyfitz I can try it on my work laptop which runs Windows 10, but I won't have access to that machine until a week from Friday. So I'll try it then, if it's still relevant.

mariusgreuel, 2022-11-24:
@jackw01 It appears that you are using a build of avrdude that contains my hacked-up version of libftdi that works with the stock FTDI drivers (as opposed to the ones requiring you to swap drivers to libusb). It seems that there is a bug that causes the chip to always operate on port A (matter of fact, the hacked library ignores the port). I will see that I get that fixed.

In the meantime, you can try forcing avrdude to use port B by specifying a serial number. If your serial number is `TG123`, you want to append a `B` for port B, i.e. `TG123B`. If you add that to your config via `usbsn = "TG123B";`, it might work.

Alternatively, you may use a MinGW build (which uses libftdi based on libusb) and then swap the FTDI driver for something libusb can work with, such as WinUSB.

securelyfitz, 2022-11-29:
@mariusgreuel Thanks! I got my hands on a W11 system, tried this, and it worked.

@jackw01 could you give this a try on your tigard? I'll bet this is the problem, not a hardware issue.

jackw01, 2022-12-16:
Yes, this fixed my issue.

Closed 2022-12-16.

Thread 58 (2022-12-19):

Deprecated OpenOCD TCL Commands

a-gavin, 2022-12-19:
As of OpenOCD version v0.11.0+ several general adapter commands [have changed](https://github.com/openocd-org/openocd/commit/5280eb618a8cab4639f1eca567472db7e5024d13) and as of v0.12.0-rc1 FTDI commands [have changed](https://github.com/openocd-org/openocd/commit/1d4b252bb16ef823d8e98bd70fc323099033898b), deprecating the older versions. This affects commands listed in the README. The deprecated commands used in Tigard's Openocd cfg files do continue to work on newer versions, but they will be phased out at some point.

Currently, the general adapter commands are up to date in the SWD config but not the JTAG config. Neither uses the current FTDI commands. Will submit a PR which fixes this shortly.

ia, 2024-12-28:
@a-gavin, is this PR still actual? Maybe someone should be ping'ed for a review since they may just did miss the notification with your pull request...

Dear @securelyfitz, @fharding1, @mossmann, @esden, @ijliao. Sorry to bother you, but could you, please, check this PR? Thanks.

securelyfitz, 2024-12-28:
Thanks for the ping. I did miss the notification at first but have to admit that I have seen nad procrastinated on this one.

My biggest dilemma is that I've got students using both openocd 10 and 11, and now 12 too.  I need to get all my class materials in sync with the differing config files for each version, and then update the Tigard docs without wiping away the old versions.

On the bright side, a config file for Tigard does now ship with openocd along with all the other interface config files, which is what I should probably be pointing people to.

a-gavin, 2024-12-30:
> On the bright side, a config file for Tigard does now ship with openocd along with all the other interface config files, which is what I should probably be pointing people to.

Good to know. It looks like the config file in OpenOCD is JTAG-specific (or at least appears to be) and only available v12+, commit [here](https://github.com/openocd-org/openocd/commit/830d70bfc66ada2a68c73283b9e4fa4770d408ee).

That I recall, the deprecated version still works for v12. Maybe OpenOCD just needs an additonal SWD-specific Tigard interface config (in addition to renaming the existing config as the JTAG version).

securelyfitz, 2025-01-17:
I am updating my training materials to use openocd 12. Once that's done, i'll update the docs, and link back to the tags for the correct 10 and 11 configurations.
One remaining factor that i have meant to figure out - where should the swd-vs-jtag decision go? Should I go with separate tigard-jtag.cfg and tigard-swd.cfg files, or should it be generic and the board/device file contain the transport definition?

a-gavin, 2025-01-17:
That's great! I'm not an in-depth user of OpenOCD, so I can't really say. I've seen a couple of examples of the transport selected in the interface TCL file (e.g. [SWD](https://github.com/openocd-org/openocd/blob/master/tcl/interface/ftdi/ashling-opella-ld-swd.cfg)/ [JTAG](https://github.com/openocd-org/openocd/blob/master/tcl/interface/ftdi/ashling-opella-ld-jtag.cfg) for the same debugger and [here](https://codingfield.com/blog/2022-08/debug-bl60x-with-openocd-and-gdb/#openocd) for just JTAG, all FTDI-based). I've done the same have done the debuggers I've used. However, I'm not this is the "correct" method, given that [other config files](https://github.com/a-gavin/openocd-confs/blob/2d918c761328c4ed0326bc595fba4592d00b2a41/esp32c6.cfg#L4) define it in the board file.

Closed 2025-01-17.

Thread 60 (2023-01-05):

Configuring for FT245 FIFO mode

svanimisetti, 2023-01-05:
Tigard is an amazing project - and I am planning to purchase it soon from CrowdSupply.

How can I configure Tigard for FT245 using the EEPROM. From the documentation, I did not find enough information on how to set configuration parameters on the EEPROM to enable "not-the-usual" programming modes? From Table 4.11 on Page 46 of the [datasheet](http://www.ftdichip.com/Support/Documents/DataSheets/ICs/DS_FT2232H.pdf), FT245 has both sync/async modes. I would appreciate if you can share documentation which show how I can use [FT_Prog](https://ftdichip.com/wp-content/uploads/2020/08/AN_124_User_Guide_For_FT_PROG.pdf) utility to set the configuration parameters on Tigard by myself.

Thanks in advance!

securelyfitz, 2023-01-05:
There's no way to use tigard in 245 mode without hardware modifications. That mode expects to use several pins as bidirectional I/O, but all the pins are hardwired to unidirectional level shifters to properly support UART, SPI, JTAG, I2C, and SWD.

If you do want to explore the additional modes, I've attached the [tigard-eeprom.conf](https://github.com/tigard-tools/tigard/files/10355433/tigard-eeprom.txt) which is used when programming the eeprom in production. The actual serial number is put in place of the x's and then it's flashed on a linux system using:
```
ftdi_eeprom  --flash-eeprom tigard-eeprom.conf
```
Similar settings should be possible with FT_Prog, but i haven't used it. You should be able to use it to read out the firmware and see how it's configured, and set the settings you're interested in.

Since 245 mode isn't possible, I'm going to close this issue as can't fix, but let me know if you have any additional questions.

Closed 2023-01-05.

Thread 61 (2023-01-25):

Connect LA port to other Logic Analysers

svanimisetti, 2023-01-25:
I recently purchased Tigard from CrowdSupply. Its a very versatile device - and I am really liking it so far! Apologies for posting this question here - as I could not find a way to contact from SecuringHardware.com.

On your [I2C video](https://learn.securinghardware.com/courses/applied-physical-attacks-with-tigard/lessons/i2c/), you demonstrated how to connect BitMagic probe to LA port on Tigard. Is there a way I could connect other logic analysers that I already own? I have a [Bitscope 10U](https://www.bitscope.com/product/BS10/) with a [SmartPort](https://www.bitscope.com/blog/DJ/08.png). Can I create an adapter between the D0-D7 pins on the Bitscope and connect it to the LA port on Tigard as shown in the [schematic](https://github.com/tigard-tools/tigard/releases/download/v1.1/tigard.pdf)? Also, which protocols can I observe in the logic analyser when I connect to the LA port?

Thanks for making this tool available as OSHW! Looking forward to your repsonse.

securelyfitz, 2023-01-26:
I'm glad you're finding tigard useful!

Yes, that's exactly what the LA port is for. While the bitmagic comes with the 14-pin harness for connecting the two, it should mate with any generic 14-pin, 1.27mm pitch, IDC-style connector. the 8 channels it connects to are the 8 channels used across all the different interfaces. some more details about the header are on the readme: https://github.com/tigard-tools/tigard#la

svanimisetti, 2023-01-26:
Looks like I missed the section on LA in the README! I think I might have to rig-up a 14-pin 1.27mm IDC to 26-pin 2.54mm IDC custom adapter. Nonetheless, I think this will be a great feature to help troubleshoot by peeking into all 5 protocols without disconnecting the target. Appreciate your prompt response. Will close the issue.

securelyfitz, 2023-01-26:
No problem! Do be careful - with the amount of wiring that might be involved, I've seen that attaching the logic analyzer harness is sometimes enough to make things noisy enough that they can't operate at full speed. Good luck.

Closed 2023-01-26.

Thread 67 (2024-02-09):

OpenOCD via SWD port on STM32F407G-DISC1 board using Tigard

svanimisetti, 2024-02-09:
I am trying to use Tigard with OpenOCD to program/debug STM32F407G-DISC1 board using the onboard 6-pin SWD port. I have researched existing issues on this repo and [articles elsewhere ](https://www.allaboutcircuits.com/technical-articles/getting-started-with-openocd-using-ft2232h-adapter-for-swd-debugging/) on the internet and got past most initial issues. However, I am currently stuck trying to resolve an error. For completeness, I am documenting all steps I have taken so far to easily reproduce the error.

1. Remove CN3 jumpers from board (see page 15 of [STM32F407G-DISC1 user manual](https://www.st.com/resource/en/user_manual/dm00039084-discovery-kit-with-stm32f407vg-mcu-stmicroelectronics.pdf)) and connect Tigard 2x5 0.05" CORTEX header pins to STM32F407-DISC1 SWD port pins is as follows:
 - VTGT->pin#1
 - SWCLK->pin#2
 - GND->pin#3
 - SWDIO->pin#4
 - nRST->pin#5
 - SWO->pin#6
2. Set power switch to 3v3 and mode switch to SWD/I2C on Tigard.
3. Installed WinUSB driver for interface 1 using [Zadig](https://github.com/pbatard/libwdi/releases/download/v1.5.0/zadig-2.8.exe) (#47). Updated from `FTDIBUS (v2.12.36.4)` to `WinUSB (v6.1.7600.16385)` [USB ID: `0403 6010 01`]
4. I am using [OpenOCD v0.12.0-2](https://github.com/xpack-dev-tools/openocd-xpack/releases/download/v0.12.0-2/xpack-openocd-0.12.0-2-win32-x64.zip). When I launch with default script that came with installation (`openocd.exe -f interface/ftdi/tigard.cfg`), I observed many errors.
> Error: session transport was not selected. Use 'transport select <transport>'
> Error: Transports available: jtag, swd
> Error: SWD mode is active but SWD_EN signal is not defined.
5. After reading the documentation and issues #54/#63, I realized that all three (interface, board and target) configurations needed to be customized for Tigard+OpenOCD+SWD for STM32 microcontrollers. I arrived at the following configuration file by combining the built-in script with notes from aforementioned issues.
```
adapter driver ftdi
adapter speed 1800
transport select swd
ftdi device_desc "Tigard V1.1"
ftdi vid_pid 0x0403 0x6010
ftdi channel 1
ftdi layout_init 0x0028 0x002b
ftdi layout_signal nTRST -data 0x0010
ftdi layout_signal nSRST -data 0x0020
ftdi layout_signal SWD_EN -data 0
#reset_config srst_only
#tigard does not support open-drain reset modes
#since its output buffer is always enabled
reset_config srst_push_pull trst_push_pull
source [find target/stm32f4x.cfg]
```
6. I ran the above script using `openocd.exe -f tigard_openocd_swd_stm32f4disc.cfg` - but got stuck at following error.
> Error: Error connecting DP: cannot read IDR
7. If I comment the last line for target definition, the OpenOCD session starts. However, I cannot run any standard commands from a telnet session. See following error.
> Open On-Chip Debugger
> > reset init
> invalid command name "reset"

If I use the on-board ST-LINK V2 interface using `openocd -f board/stm32f4discovery.cfg` (after reconnecting the CN3 jumper), I don't have any issues with flashing firmware or debugging. I would appreciate any guidance on how to resolve this issue. Since this board does not have JTAG interface, I would like to find a way to use Tigard via OpenOCD with SWD.

securelyfitz, 2024-02-09:
There have been a few changes in the config files for openocd 11 and 12. I haven't tested them myself, but as of 11, tigard.cfg should be in interface/ftdi/tigard.cfg. You are correct, there's more than just the tigard cfg. stuff like swd vs jtag varies based on your target, so it can't be a part of the generic tigard cfg.

I'd recommend running something more like:
`-f interface/ftdi/tigard.cfg -f target/stm32f4x.cfg`
so you can stick to the generic files.

I have used tigard on an stm32 'blue pill' using openocd 10 and only vcc,gnd,swck, and swdio, so i know it should be possible.

my best guess at what's going on with your current issue is that tigard is properly configured, but for some reason, you're not getting the expected response from the stm32. That's why openocd gives you a prompt with none of the 'cpu' commands.

Can you try hooking tigard back up and using the 'targets' command in openocd?

Also - are the reset and swo pins necessary? If so - what are they connected to on tigard?

Do you know if your stm32 is actually running and not currently in reset for some reason?

svanimisetti, 2024-02-09:
I disconnected the nRST and SWO pins from Tigard - and tried using generic files using your suggestions. However, I get a different error.

```
>C:/apps/openocd-v0.12.0/bin/openocd.exe -f interface/ftdi/tigard.cfg -f target/stm32f4x.cfg
Open On-Chip Debugger 0.12.0 (2023-01-14-23:37)
...
Error: JTAG scan chain interrogation failed: all ones
Error: Check JTAG interface, timings, target power, etc.
Error: Trying to use configured scan chain anyway...
Error: stm32f4x.cpu: IR capture error; saw 0x0f not 0x01
Warn : Bypassing JTAG setup events due to errors
Error: Invalid ACK (3) in DAP response
```

Perhaps generic/default configuration files are setup for JTAG interface. When I use my custom SWD configuration, OpenOCD runs, but the output of `targets` command is also empty. The STM32 is currently running as I flashed a simple blinky firmware to test/debug this issue. I am guessing that I need to manually add the target definition for stm32f4x to get this to work.

securelyfitz, 2024-02-09:
oh, oops. The generic file doesn't have the swd/jtag choice, and neither does the generic stm file.
I have had multiple inconclusive conversations about this - does the transport select go with the adapter or the target... I have generic, jtag, and swd config files for tigard sitting in my path and use all three of them on different occasions. the one that made it into openocd is the one without the transport selected.

svanimisetti, 2024-02-09:
I found that @ruswernet posed a [custom configuration for SWD](https://github.com/tigard-tools/tigard/issues/63#issuecomment-1819740933) on #63. He was using a rp2040. I tried using his configuration with the stm32f4x target. But even that gave the same original error I reported.

```
>openocd.exe -f tigard-swd.cfg -f target/stm32f4x.cfg
Open On-Chip Debugger 0.12.0 (2023-01-14-23:37)
...
Error: Error connecting DP: cannot read IDR
```

securelyfitz, 2024-02-09:
good news: you're not the only one with the problem
bad news: they didn't solve it

https://community.platformio.org/t/stm32-programming-with-ft2232h-via-swd-encounter-error-connecting-dp-cannot-read-idr/36766

svanimisetti, 2024-02-09:
Thanks! I was aware of this issue and researched the steps the OP documented in his post. Nonetheless, I have posted on that thread to see if the OP has an update!

svanimisetti, 2024-02-09:
Resolved the issue using notes from [here](https://electronics.stackexchange.com/questions/182763/how-to-use-an-external-st-link-v2-with-the-stm32f4-discovery-board/410840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) and [here](https://electronics.stackexchange.com/questions/230036/problems-connecting-st-link-v2-and-stm32f4-discovery-board). I updated the firmware on the discovery board using the [STM32CubeProgrammer](https://www.st.com/en/development-tools/stm32cubeprog.html) utility to V2J43M28. Also, made sure the board is only powered using VDD and the USB is disconnected from onboard ST-LINK V2.

Now I am able to use `tigard-swd.cfg` posted in #63 with standard target script `stm32f4x.cfg` (`openocd.exe -f tigard-swd.cfg -f target/stm32f4x.cfg`). Running `targets` via OpenOCD now lists the microcontroller.

```
Open On-Chip Debugger
> targets
    TargetName         Type       Endian TapName            State
--  ------------------ ---------- ------ ------------------ ------------
 0* stm32f4x.cpu       cortex_m   little stm32f4x.cpu       running
```

Closed 2024-02-09.

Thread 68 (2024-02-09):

OpenOCD via JTAG port on SiFive HiFive1 Rev B02 board using Tigard

svanimisetti, 2024-02-09:
This issue is related to #67.

I am trying to use Tigard with OpenOCD to program/debug SiFive HiFive1 Rev B02 via JTAG interface. This board is based on the RISC-V FE310-G002 microcontroller. The board has an on-board 2x5 0.05" CORTEX header with JTAG interface.  See [user manual](https://www.starfivetech.com/uploads/hifive1b-getting-started-guide_v1.2.pdf) for more information.

1. Connect Tigard with HiFive1 board using standard cable supplied with Tigard
2. I have already installed WinUSB driver for interface 1 using [Zadig](https://github.com/pbatard/libwdi/releases/download/v1.5.0/zadig-2.8.exe) (#47). Updated from `FTDIBUS (v2.12.36.4)` to `WinUSB (v6.1.7600.16385)` [USB ID: `0403 6010 01`]
3. Set power switch to 3v3 and mode switch to JTAG/SPI on Tigard.
4. I am using [OpenOCD v0.12.0-2](https://github.com/xpack-dev-tools/openocd-xpack/releases/download/v0.12.0-2/xpack-openocd-0.12.0-2-win32-x64.zip). When I launch with default script that came with installation (`openocd.exe -f board/sifive-hifive1-revb.cfg -f interface/ftdi/tigard.cfg`), I observed the following error.
> Error: No J-Link device found
5. Also, if I change the order of the arguments when I pass the scripts, the error is different.
> Error: invalid command name "jlink" in procedure 'script' at file "embedded:startup.tcl", line 28

Based on the previous experience with STM32, I am assuming that standard/generic configuration files may not be sufficient for interfacing the board with Tigard using OpenOCD. I could not find any issues reported on this repo with RISC-V microcontrollers or JTAG interface - so any suggestions would be greatly appreciated!

svanimisetti, 2024-02-09:
Posted the issue a little too soon. I did not realize that [response](https://github.com/tigard-tools/tigard/issues/54#issuecomment-1143667915) to #54 by @Seas0 already listed a JTAG configuraiton file. I just combined it with the default configuration (board/sifive-hifive1-revb.cfg) to arrive at an FTDI configuration.

```
# This script combines the following:
#C:\apps\openocd-v0.12.0\share\openocd\scripts\interface\ftdi\tigard.cfg
#C:\apps\openocd-v0.12.0\openocd\scripts\board\sifive-hifive1-revb.cfg

adapter driver ftdi
adapter speed 4000
transport select jtag
ftdi device_desc "Tigard V1.1"
ftdi vid_pid 0x0403 0x6010
ftdi channel 1
ftdi_layout_init 0x0038 0x003b
ftdi_layout_signal nTRST -data 0x0010
ftdi_layout_signal nSRST -data 0x0020
reset_config trst_and_srst separate srst_nogate trst_push_pull srst_push_pull

set _CHIPNAME riscv
jtag newtap $_CHIPNAME cpu -irlen 5 -expected-id 0x20000913
set _TARGETNAME $_CHIPNAME.cpu
target create $_TARGETNAME.0 riscv -chain-position $_TARGETNAME
$_TARGETNAME.0 configure -work-area-phys 0x80000000 -work-area-size 0x4000 -work-area-backup 0
flash bank onboard_spi_flash fespi 0x20000000 0 0 0 $_TARGETNAME.0
init
```

Running using `openocd.exe -f tigard_openocd_jtag_sifive_hifive1_revb02.cfg` following with `targets` via telnet listed the board!

```
> targets
    TargetName         Type       Endian TapName            State
--  ------------------ ---------- ------ ------------------ ------------
 0* riscv.cpu.0        riscv      little riscv.cpu          running
```

svanimisetti, 2024-02-09:
Resolved using combination of default scripts and solution from #54

Closed 2024-02-09.

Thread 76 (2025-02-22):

Question, how does the FT232 exactly select modes? How does this board implement it in hardware

HasanTheSyrian, 2025-02-22:

securelyfitz, 2025-02-23:
It depends on what you mean by the modes.

The "mode switch" on the board that switches between jtag/spi and i2c/swd basically connects the poci/tdo pin to the pico/tdi pin with a 330 ohm resistor.
This is because both i2c and swd have a bidirectional data pin, so we need to be able to both read and write to it, but the FT2232H does not really support that.

If you mean switching between spi and jtag and i2c and swd for the different tools - that's all taken care of by the software tools. The FTx232H family all support MPSSE, which is their way of doing high throughput I/O. That's what PyFtdi, flashrom, openocd, and others all use to make the ft2232h speak their protocol.

Does this answer your question? Let me know if you want more details on any part.

-joe

HasanTheSyrian, 2025-02-23:
I should've been clearer on what I'm trying to do. Im trying to use an FT232 breakout board (CJMCU FT232H specifically) to try to program my Xilinx FPGA dev board. I'm trying to see if I can program/debug it + my Mac because I'll be studying a semester away from my Windows PC.

I'm also trying to get familiar with the chip because I'll implement it as a USB-JTAG (where you can also switch the JTAG mode off and use the USB port as normal USB device) programmer on my custom FPGA development board.

My aim is for it to be recognized by Xilinx tools directly (w/o using OpenOCD etc). It seems that the switch on your board is a workaround for the FT2232 and the selection for JTAG is done via software (can/does the IC get programmed once to use JTAG?). Im also confused on this, it seems that pins of the same communication protocol are on different selections of the switch.

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

*my breakout board hasn't arrived yet so I haven't had the chance to try it but I'm trying to understand how everything works in general

securelyfitz, 2025-02-23:
Tigard uses the FT2232H, not the FT232H. They're similar, but since you're using a different board based on a different chip, this isn't the right place to find the answer.

You *should* bug xilinx to tell them to stop going out of their way to block certain hardware from working natively. You could look into an alternative like openfpgaloader which supports tigard, all of the ftx232h family, and xilinx fpgas. I haven't dealt with xilinx tools in ages, but something similar to [this](https://gist.github.com/rikka0w0/24b58b54473227502fa0334bbe75c3c1) worked for me with ISE 10+ years ago to get FT232H working natively.

More discussion and explanation about the mode switch can be found in issue #5, however that's not likely what you want since that's all about i2c and swd.

You're probably looking for how to use the ft232h to interface an fpga board, your best bet would be to study how it's done on a similar board. Icebreaker is one example, though it uses lattice fpga and open source toolchain and loader. Digilent makes xilinx boards that work natively with ISE but they used to be pretty cagey about how it was wired up.

Closed 2025-02-23.

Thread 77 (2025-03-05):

Flash error with ESP32 LyraT v4.3 Board

cody328, 2025-03-05:
I am trying to flash the ESP32 LyraT v4.3 board with Tigard, but I am unable to successfully flash the firmware.

The command idf.py -p COM7 monitor works properly, but the flashing command does not execute successfully.
I have attempted both methods: using version 3.3 of Tigard and providing an external voltage supply to the LyraT board. Additionally, I switched to the VTGT setting on the Tigard board.

Could anyone provide assistance or suggestions on how to resolve this issue?

securelyfitz, 2025-03-05:
i don't have any experience with that board or with idf.py, but some questions/ideas:

- are you getting any error messages?
- does it work with other programming devices on that board? if so, which ones?
- does it work with other boards using tigard? if so, which one?
- does it work with tigard and that board using a different flashing tool, like esptool or the web-based flasher?

that should help narrow down where the issue lies

cody328, 2025-03-18:
Sorry for late reply.
Can we discuss via whatsapp?

securelyfitz, 2025-04-04:
cody,
If you were able to resolve this could you share what the solution was in case others have a similar issue?

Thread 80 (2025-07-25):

How to Dump EEPROM Contents from Tigard for Flashing to Custom FT2232H Board's EEPROM

santhoshgandham, 2025-07-25:
Hi Team,

I'm currently working on a custom FT2232H-based debugger board that mimics the Tigard design. I'm using the same ICs (FT2232H) and have followed the same pin configurations and logic layout.

To ensure firmware/software compatibility, I would like to replicate the exact EEPROM contents of the Tigard board and flash them into my custom board.

Could you kindly share how I can:
1. Dump the complete EEPROM content from an original Tigard board, and
2. Use that dump to program another FT2232H-based device.

I’ve tried using `ftdi_eeprom` and `libftdi1`, but I'm unclear on how to extract the EEPROM as-is (including string descriptors, CBUS settings, etc.).

Any guidance, EEPROM binary/hex dump, or `.conf` file would be immensely helpful.

Thanks in advance!

Best regards,
Santhosh

securelyfitz, 2025-07-25:
ftdi_eeprom is weird, it needs a config file to read or to write the
eeprom. Below is most of the config file I use. Be sure to change the
manufacturer and product strings, as well as the serial number. Details on
the serial number:
https://github.com/tigard-tools/tigard?tab=readme-ov-file#serial-numbers

-joe

> ftdi_eeprom --flash-eeprom tigard.conf

tigard.cfg:

vendor_id=0x403
product_id=0x6010

# Max. power consumption: value * 2 mA. Use 0 if self_powered = true.
max_power=500

###########
# Strings #
###########
manufacturer="CHANGEME"
product="CHANGEME"

###########
# Options #
###########
self_powered=false  # Turn this off for bus powered
remote_wakeup=false # Turn this on for remote wakeup feature
use_serial=true     # Use the serial number string

# Normally out don't have to change one of these flags
in_is_isochronous=false     # In Endpoint is Isochronous
out_is_isochronous=false    # Out Endpoint is Isochronous
suspend_pull_downs=false    # Enable suspend pull downs for lower power
change_usb_version=false    # Change USB Version
usb_version=0x0200          # Only used when change_usb_version is enabled

eeprom_type=0x56

########
# Misc #
########

# This is the relative filename that EEPROM contents will either be
# read from or written to, depending on whether ftdi_eeprom is run
# with the --read-eeprom or --flash-eeprom option.
filename="eeprom.bin"

serial="CHANGEME"

On Fri, Jul 25, 2025 at 1:03 AM Santhosh Gandham ***@***.***>
wrote:

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

santhoshgandham, 2025-07-25:
Thanks a lot for the for the replyvand I've programmed the eeprom of my custom board Firmex with this as you said and named it with tigard.conf:

vendor_id=0x403
product_id=0x6010
max_power=500
manufacturer="SecuringHardware"
product="Tigard V1.1"
self_powered=false
remote_wakeup=false
use_serial=true
in_is_isochronous=false
out_is_isochronous=false
suspend_pull_downs=false
change_usb_version=false
usb_version=0x0200
eeprom_type=0x56

serial="TG110001"

I'm trying to connect to a target microcontroller (LM3S series ARM Cortex-M3) via JTAG using OpenOCD. I have two FT2232H-based boards:
1. **A Tigard board**
2. A custom **Firmex** Debugger board (VID:PID 0403:6010, serial TG110001)

**My goal is to interrogate the JTAG chain and dump data.**  I’m using the following OpenOCD config file (jtag_dump.cfg):

adapter driver ftdi
transport select jtag
ftdi_vid_pid 0x0403 0x6010
ftdi_channel 1
ftdi_layout_init 0x0038 0x003b
ftdi_layout_signal nTRST -data 0x0010
ftdi_layout_signal nSRST -data 0x0020
reset_config trst_and_srst separate srst_nogate trst_push_pull srst_push_pull
adapter speed 500
source [find target/stellaris.cfg]

**✅ With Tigard, the following output is seen:**

**$ sudo openocd -f jtag_dump.cfg**
Open On-Chip Debugger 0.11.0
Info : Listening on port 6666 for tcl connections
Info : Listening on port 4444 for telnet connections
Info : clock speed 500 kHz
Info : JTAG tap: lm3s.cpu tap/device found: 0x4ba00477 (mfg: 0x23b (ARM Ltd), part: 0xba00, ver: 0x4)
Info : lm3s.cpu: hardware has 6 breakpoints, 4 watchpoints
Info : starting gdb server for lm3s.cpu on 3333

**❌ With Firmex Debugger, using the same config and wiring:**

**$ sudo openocd -f jtag_dump.cfg**
Open On-Chip Debugger 0.11.0
Info : clock speed 500 kHz
Warn : There are no enabled taps
Error: JTAG scan chain interrogation failed: all ones
Error: Check JTAG interface, timings, target power, etc.
Error: Trying to use configured scan chain anyway...
Error: lm3s.cpu: IR capture error; saw 0x0f not 0x01
Error: Invalid ACK (7) in DAP response

lsusb -v -d 0403:6010 | grep -E 'iManufacturer|iProduct|iSerial'

  iManufacturer           1 SecuringHardware
  iProduct                2 Tigard V1.1
  iSerial                 3 TG110001

**What I want to understand:**
Why does the Tigard board work flawlessly with the same jtag_dump.cfg, connections, and target, while the Firmex debugger fails?

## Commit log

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2020-05-14 Basic power schematic (USB, LDOs, LEDs, Switches)
    * USB Type-C connector
    * 3.3v and 1.8v LDOs
    * Vset and Vtarget switch circuitry
    * Power LED, Vtarget LED
    [tigard.sch]
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2020-05-15 Add JTAG, UART, SPI, SWD, I2C connectors
    [tigard.sch]
2020-05-15 Add FT2232H and EEPROM to schematic
    [tigard.sch]
2020-05-15 Initial work for input/output buffers
    * Still need to decide on a footprint for them
    [tigard.sch]
2020-05-19 Add RHL-24 footprint for buffers
    [tigard.sch]
2020-05-19 Add I2C/SWD switch, RX/TX and ENABLE LEDs
    * Also adds another 2.2uF capacitor to VREGOUT
    * Fixes some DRC complaints
    * Adds aliases (wiring)
    [tigard.sch]
2020-05-19 Add missing part numbers for FT2232HQ
    * Also add csv# to .gitignore for libreoffice CSV temp files
    [tigard.sch]
2020-05-19 Add mounting holes to schematic
    [tigard.sch]
2020-05-19 Re-annotate (fix reference ordering)
    [tigard.sch]
2020-05-19 Add PAD (pin 25) to buffer footprint
    [tigard.sch]
2020-05-23 Four position 1.8v, 3.3v, 5v, VTARGET switch
    [tigard.sch]
2020-05-23 Add VTARGET -> VREF jumper
    [tigard.sch]
2020-05-23 Add SecuringHW and OSHW logo
    * SecuringHardware logo footprint is from
    https://github.com/esden/pretty-kicad-libs @esden said it could be
    used in this project
    [tigard.sch]
2020-05-23 Reorder UART connector, smaller JTAG header
    [tigard.sch]
2020-05-23 Fix RHL-24 footprint pinout
    What should've been pin 12 was pin 24.
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2020-05-24 Add Key field to schematic symbols
    * Switch from 0603 2u2 to 0402 2u2 for everything
    * Change 93LC56BT to 93LC46BT but keep 56 LCSC part number since LCSC
    only has 56
    [tigard.sch]
2020-05-24 Layout routing complete, RHL fixes, xtal caps
    * Finish first round of routing (needs to be reviewed, reworked in some
    places probably)
    * Fix the RHL footprint (paste shouldn't be copper layers, thermal pad
    should be a polygon)
    * Add 30pF capacitors to the xtal (based off estimated Cstray of 5pF)
    [tigard.kicad_pcb, tigard.sch]
2020-05-27 Redesign
    * Designed completely in metric, no mixing units
    * RoundRect pads
    * Comb for resistor arrays
    * VREG on inner power layer
    * Switch to SMD SWD connector
    * OSHW logo on front & back
    * License and copyright info
    * Remove reference designators
    [tigard.kicad_pcb, tigard.sch]
2020-05-28 Move vias out from underneath FT2232H
    [tigard.kicad_pcb, tigard.sch]
2020-05-29 Revise design to use cheaper TSSOP buffer footprint
    [tigard.kicad_pcb, tigard.sch]
2020-05-29 Add USB filtering
    * Ferrite and capacitor on VBUS per FTDI spec
    * NF resistor and capacitor on shield to GND per FTDI spec
    [tigard.kicad_pcb, tigard.sch]
2020-05-29 Fix buffer symbol (remove PAD)
    [tigard.kicad_pcb, tigard.sch]
2020-05-30 Fiddle with labels, add thermal reliefs, add 3D
    * VT -> TARGET on switch
    * Thermal reliefs for everything but thermal pad vias
    * USB C CAD model
    * FTDI CAD model
    * Align SWD connector
    [tigard.kicad_pcb, tigard.sch]
2020-05-30 Reorder LEDs: PWR, EN, REF
    [tigard.kicad_pcb]
2020-05-30 Obvious pinheader pin1 markings
    [tigard.kicad_pcb, tigard.sch]
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2020-05-31 Mostly BOM related changes. Made the shield/gnd resistor a 1M.
    [tigard.kicad_pcb, tigard.sch]
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2020-06-02 Added project name and version on silkscreen and sheet legends.
    Also added the default gerber output directory setting.
    [tigard.kicad_pcb, tigard.sch]
2020-06-02 Generate protel suffix gerber file names.
    [tigard.kicad_pcb]
2020-06-02 Fix buffer part number (PWR not RHL)
    [tigard.sch]
2020-06-05 Some gerber generation parameter tweaking and replacing remaining rect to roundrect pads.
    [tigard.kicad_pcb]
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2020-06-14 Add pull-down resistor for REF LED MOSFET
    Since there was no pull-down resistor on the mosfet for the reference
    voltage LED it would behave unpredictably when connected to an unpowered
    target in target mode. Closes #6
    [tigard.kicad_pcb, tigard.sch]
2020-06-14 Cleanup VCC/VTGT/VREF/etc naming on silk
    * LED "REF" -> VTGT
    * Header VCC -> VTGT
    * Jumper VTARGET -> VTGT
    * Switch VTARGET -> VTGT
    * Labels switch "TARGET"
    Part of #9
    [tigard.kicad_pcb]
2020-06-14 Improve mode switch labeling
    * Adds I2C under SWD
    * Adds SPI under JTAG
    * Adds a "MODE" label for the whole switch
    Closes #8
    [tigard.kicad_pcb]
2020-06-14 Use more LED colors
    * PWR is now yellow to indicate "powered but not yet ready"
    * EN is now green to indicate "ready"
    * PWR is still blue to indicate "energized" (this is the most important
    LED so I like using a bright color like blue)
    * UART RX is green, TX is yellow, same colors an ethernet port would use
    for rx/tx
    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
    [tigard.kicad_pcb, tigard.sch]
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2020-06-17 New header wiring, logic analyzer, silk docs
    * Revised silkscreen to include: mode switch meanings, vtarget selection
    info, vref/vtarget isolation, flashrom command, and pin assignments
    (closes #10)
    * Consolidated VCC/VTGT/VREF naming (closes #9)
    * Revised mode selection switch to support connecting SWD hack resistor
    as well as support using the SWD connector as a full CORTEX connector
    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
    [tigard.kicad_pcb, tigard.sch]
2020-06-19 Moved mounting holes and cuts on the metric grid. Added dimensions.
    [tigard.kicad_pcb]
2020-06-19 Shrunk outline to a round 46mm, moved to a round corner position.
    [tigard.kicad_pcb]
2020-06-30 Replace all instances of MISO/MOSI with CIPO/COPI
    https://www.oshwa.org/a-resolution-to-redefine-spi-signal-names
    Closes #12
    [tigard.kicad_pcb, tigard.sch]
2020-06-30 fixing swapped JTAG and SPI in the pinout table
2020-07-14 Add DP4T switch model, roundrect THT
    [tigard.kicad_pcb]
2020-07-31 Add Qwiic/stemma qt connector (closes #14)
    [tigard.kicad_pcb, tigard.sch]
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2020-07-31 Rename QWIIC connector to I2C
    [tigard.kicad_pcb, tigard.sch]
2020-08-07 Connect LA header to GND (closes #21)
    [tigard.kicad_pcb, tigard.sch]
2020-08-10 Add CDONE pin for iCE programming (#15)
    [tigard.kicad_pcb, tigard.sch]
2020-08-15 adding logo and incrementing version
    [tigard.kicad_pcb]
2020-08-25 fixing 1.27mm header part numbers
    [tigard.sch]
2020-08-27 fixing uart header component; JTAG header label
    [tigard.kicad_pcb, tigard.sch]
2020-08-28 fixing jtag footprint and silk; uart header orange
    [tigard.kicad_pcb]
2020-09-03 modify usb footprint for paste-in-hole closing #25
    [tigard.kicad_pcb]
2020-09-06 Fix USB C footprint (update in library)
    [tigard.kicad_pcb]
2020-09-10 Move USB C RC circuit further away from connector
    [tigard.kicad_pcb]
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2020-10-28 Fix bypass cap
    [tigard.kicad_pcb]
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2020-11-13 changing 2u2 capacitor part number to a 0402 that fits
    [tigard.sch]
2020-11-13 Fix VBUS trace size (0.205mm -> 0.25mm)
    [tigard.kicad_pcb]
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2020-12-07 Fix 1Mohm res part number, remove incorrect LA P/N
    Closes #34
    [tigard.sch]
2021-03-24 fixing i2c terminology oops
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2021-11-18 fixing i2c toc entry
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2022-01-04 fixing swd reset pin state
    Issue #51 points out the rest pin is held by the swd openocd config file. Fixing ftdi_layout_init to fix it.
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2025-10-13 Update README.md
    removing reference to the I2C HACK jumper that doesn't work as intended, closing #53
